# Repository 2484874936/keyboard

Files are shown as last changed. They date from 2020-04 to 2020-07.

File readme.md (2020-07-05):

**@版权所有->刘威**

**[SEASKY机械键盘演示视频](https://b23.tv/BV1ri4y1t7xG)**

**[程序完善，键盘部分完整功能视频，和普通键盘效果差不多](https://b23.tv/BV1Pz411z7MM)**

**software如果使用cube重新生成过程序，请用备份里的ST文件替换Middlewares目录下的ST文件**

**欢迎加入SEASKY开源技术交流群:893445794**

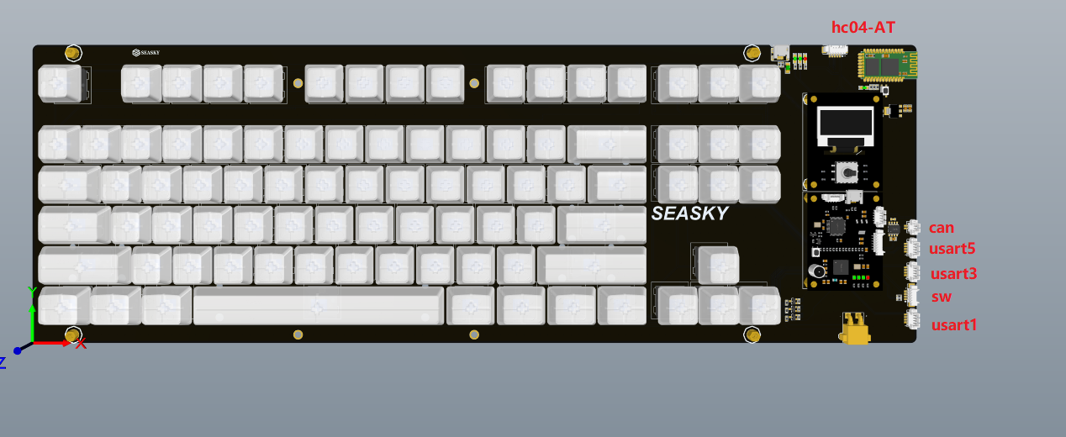
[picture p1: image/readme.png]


**说明：**
	上图所示引出接口，普通接口使用GH1.25，SWD调试接口使用MX1.25,如果你使用的J-link，或ST-link是2.54的，需要买相应的2.54转mx1.25的线，如果你使用其他烧录方式，具体自己了解，最后提醒一下，务必关注原理图接口线序，我做的接口基本兼容RoboMaster，注意蓝牙模块必须是HC04-HID模块

**下载说明：**
	因为有人反映github下载速度过慢，因此如果您有下载网速过慢的问题可以尝试使用码云[``https://gitee.com/``](https://gitee.com/)clone仓库后下载，码云下载github仓库的具体方法大家自行了解，很简单,同时由于仓库可能会更新软件，建议大家在github关注。
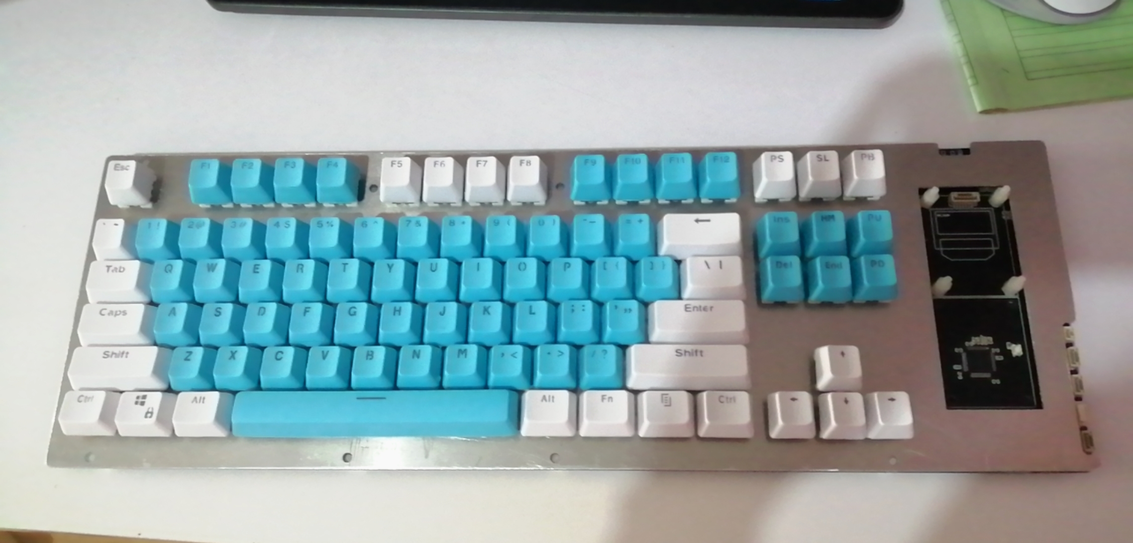
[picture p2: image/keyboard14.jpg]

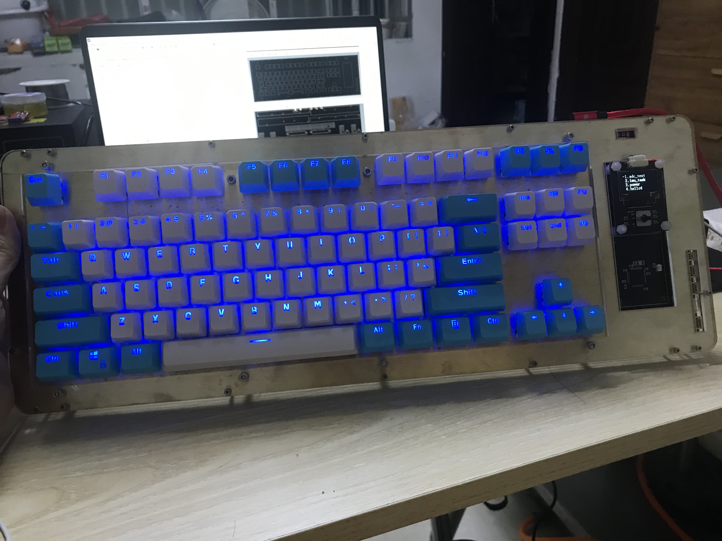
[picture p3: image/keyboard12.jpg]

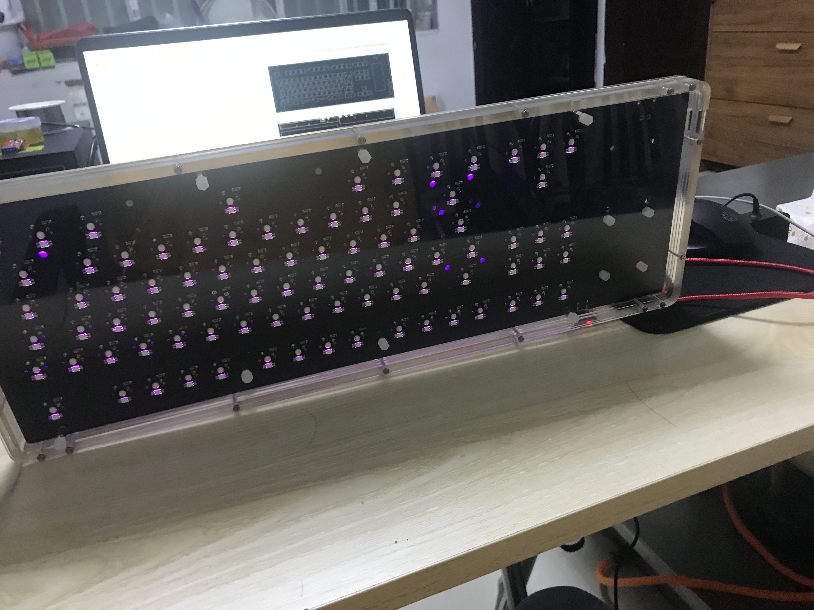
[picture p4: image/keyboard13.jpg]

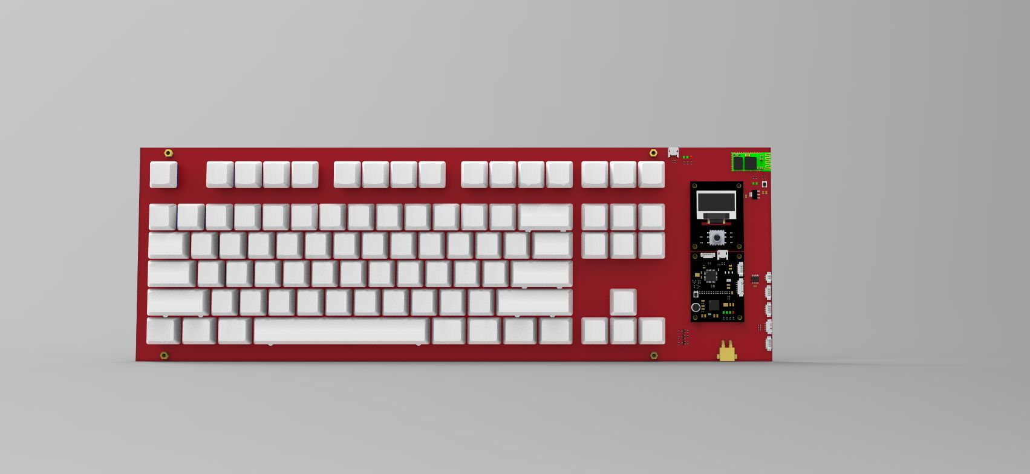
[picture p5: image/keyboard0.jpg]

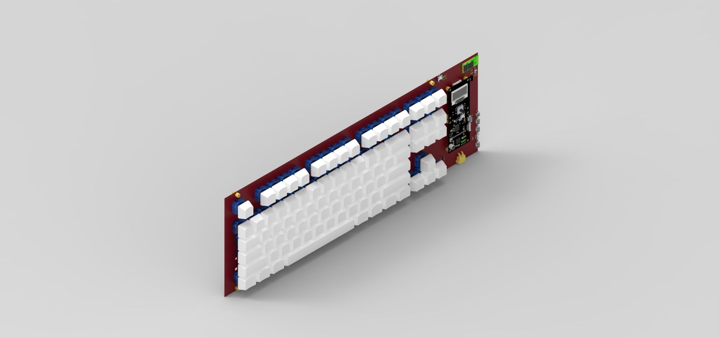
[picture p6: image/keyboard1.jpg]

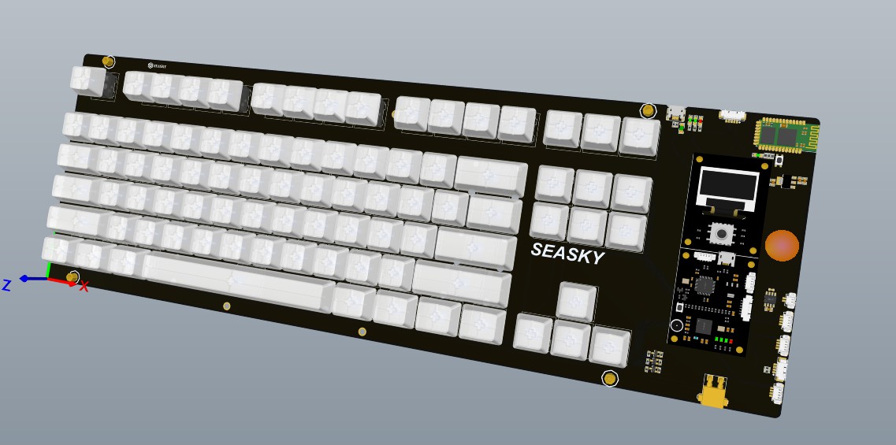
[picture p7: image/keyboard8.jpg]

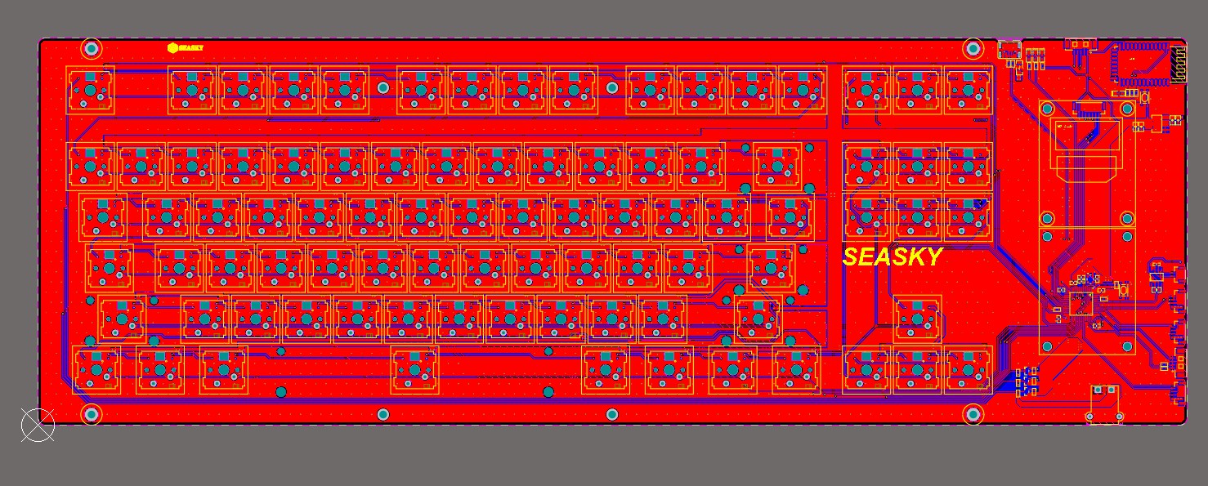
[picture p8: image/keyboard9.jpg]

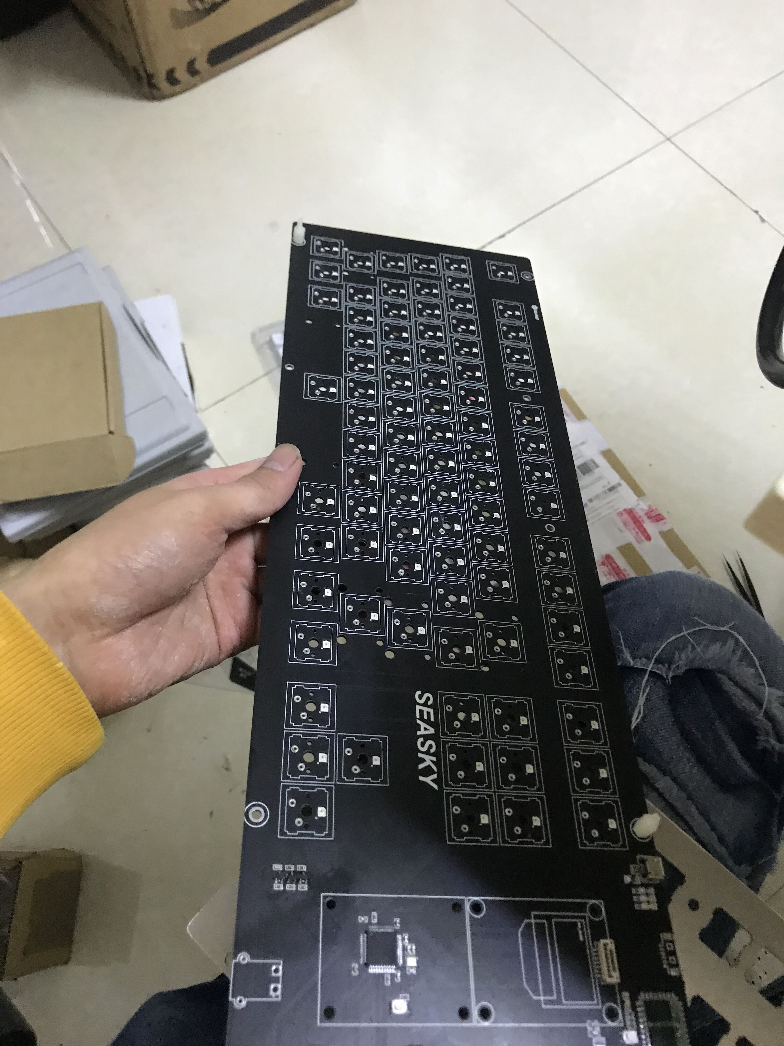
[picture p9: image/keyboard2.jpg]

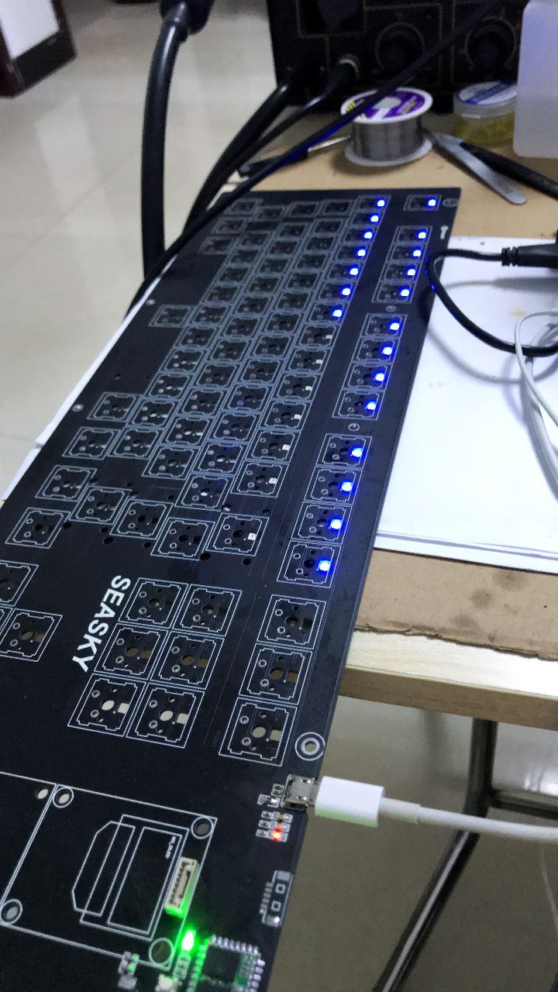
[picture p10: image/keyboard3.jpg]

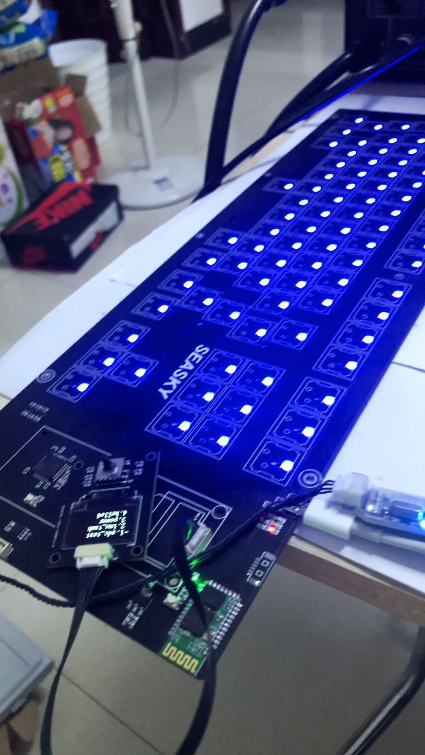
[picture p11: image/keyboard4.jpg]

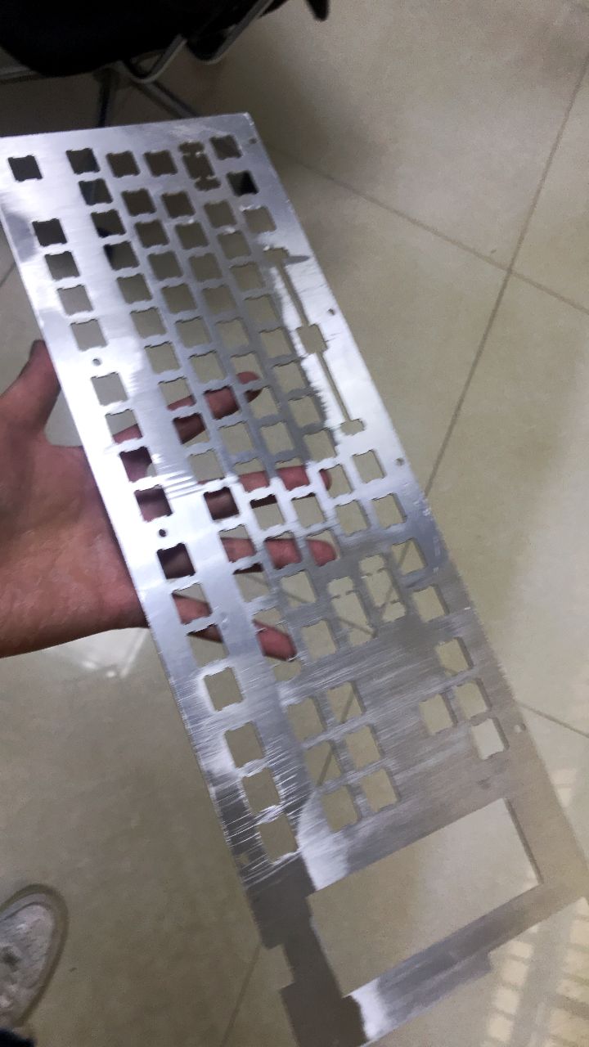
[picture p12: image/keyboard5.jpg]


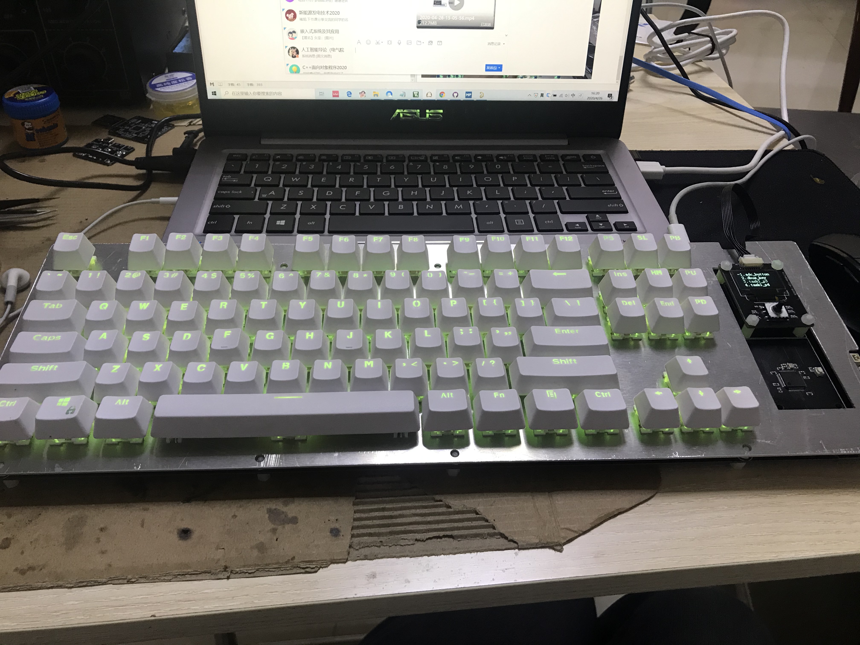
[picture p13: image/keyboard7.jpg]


**定位板：可以发加工黄铜定位板，铝定位板，此定位板可能需要自行修改一下，否则可能导致部分usb数据线无法接入**
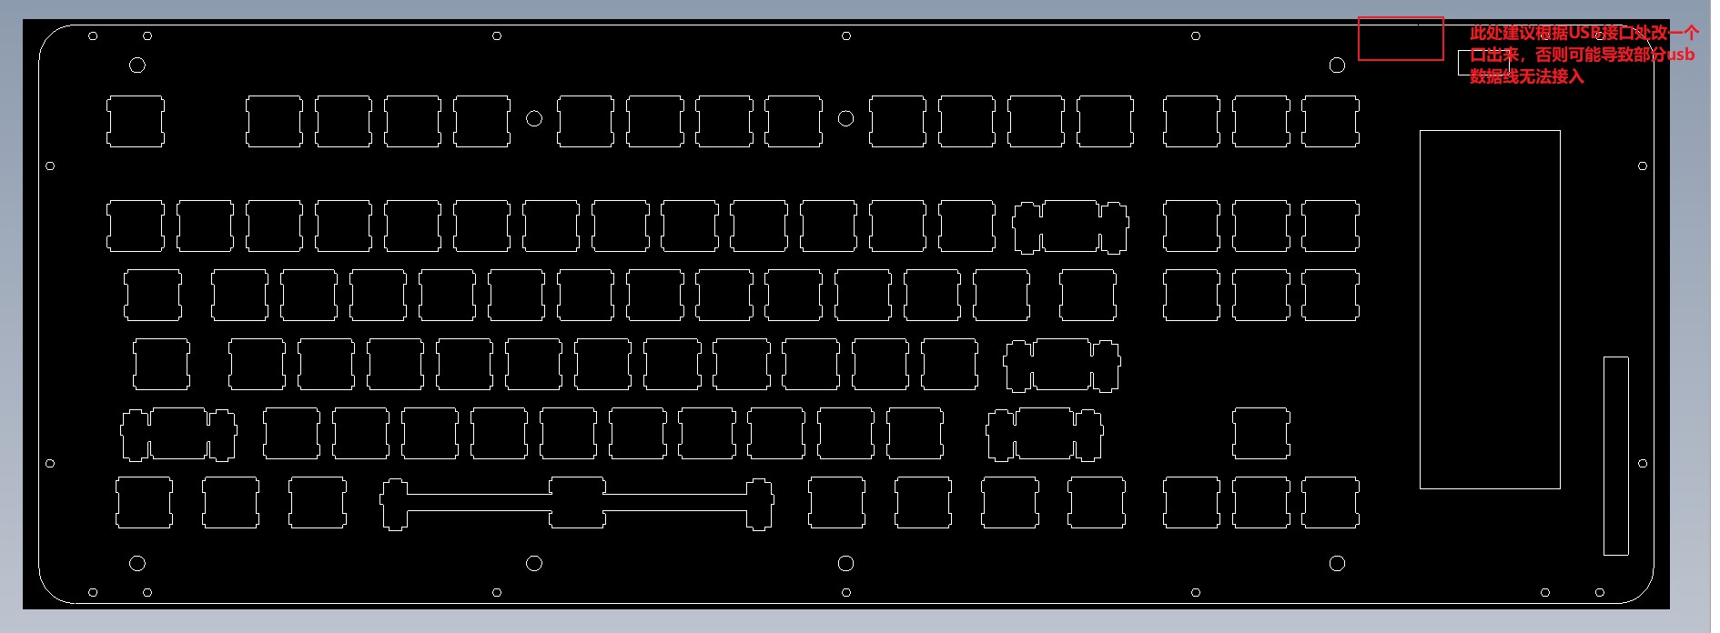
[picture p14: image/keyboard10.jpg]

**亚克力外壳：发亚克力加工 M2 M3螺丝**
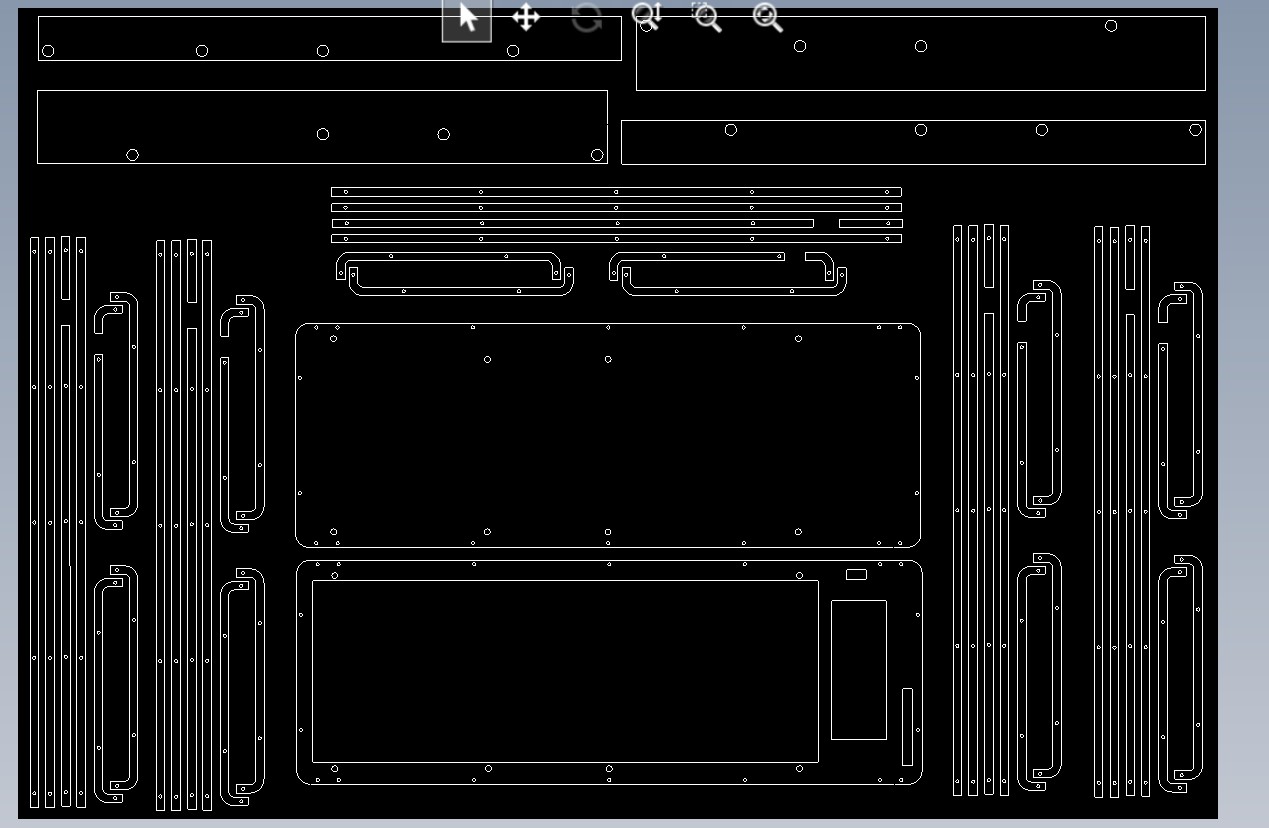
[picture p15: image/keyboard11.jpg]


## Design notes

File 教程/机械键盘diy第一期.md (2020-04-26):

##机械键盘DIY教程第一期
**@版权所有->SEASKY**

**LICENSE:** **MIT License**
##
> 看了一些网上的机械键盘diy教程，大都是用买的pcb和元件来焊接，pcb由联系厂家定制，现在我们来一个完全的，正真意义上的DIY教程，从元件选取，到PCB布局，再到焊接，完全可以自己一个人实现。
> 

#1.0原理部分
	1.1.本机械键盘选择使用stm32的usb-hid实现有线的hid键盘通信。
	1.2.选择使用蓝牙HID模块HC-04实现无线HID通信功能(具体情况淘宝搜索蓝牙HID模块就能找到啦)。
	1.3.键盘使用按键扫描。
	1.4.机械键盘看情况是否需要RGB灯效，我这里是做了RGB灯的选择的RGB是比较流行的WS2812B，封装选的和
	普通RGB大小一样的3512，当然为了能把LED贴在轴体里面还选择了反贴的3512封装，这个封装也可以叫6028，
	它相比比其他的优点:毫无疑问控制方面，节省IO资源；6028封装方便贴片。具体见后面分析。
	1.5.程序部分就不在这里说了。
	1.6.无线需要电源，我只留了接口，自己买个电池，做个dcdc到5v即可扩展。
	1.7.预留了一些接口包括OLED，串口，can等，方便扩展功能，我这里做的是一个LD3320语音识别模块。

#PCB绘制教程

----------

#1.首先需要找到机械键盘轴体的封装：


#上面是我从淘宝中找的图下面是pcb封装，pcb封装库我直接用的gh60的cherry轴元件库，大多数轴体都是兼容的
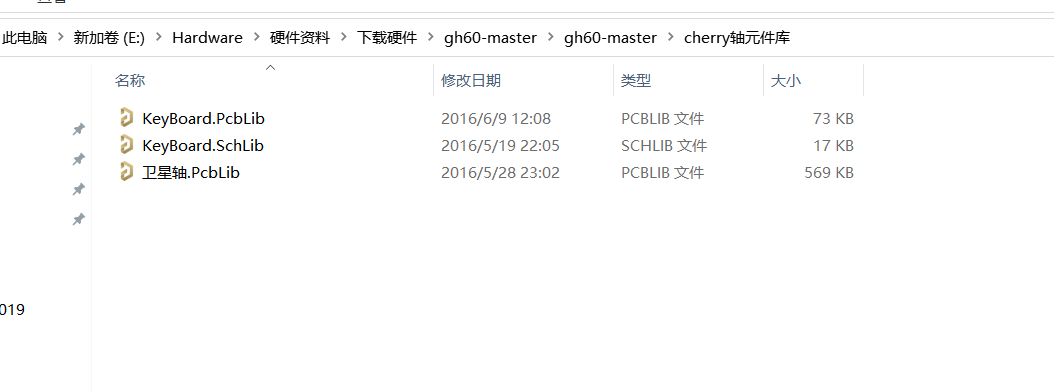
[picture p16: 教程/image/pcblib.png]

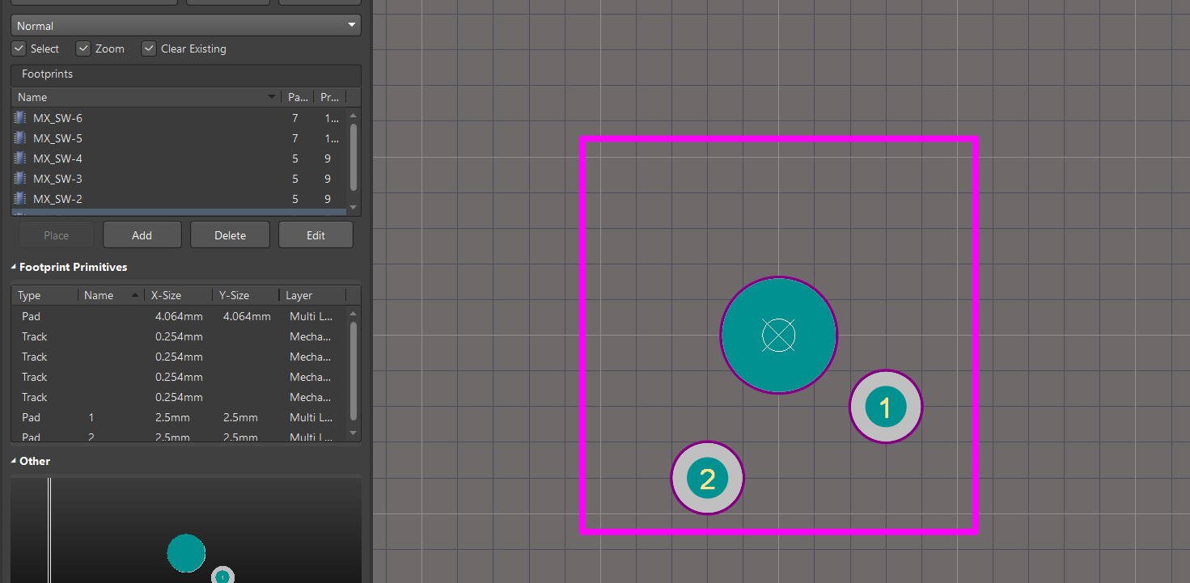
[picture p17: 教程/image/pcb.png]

#当然遗憾的是GH60开源的封装库里面没有3d封装，接下来我们需要稍稍更改一下这个，需要把3512led的封装集成到里面去
#更改前
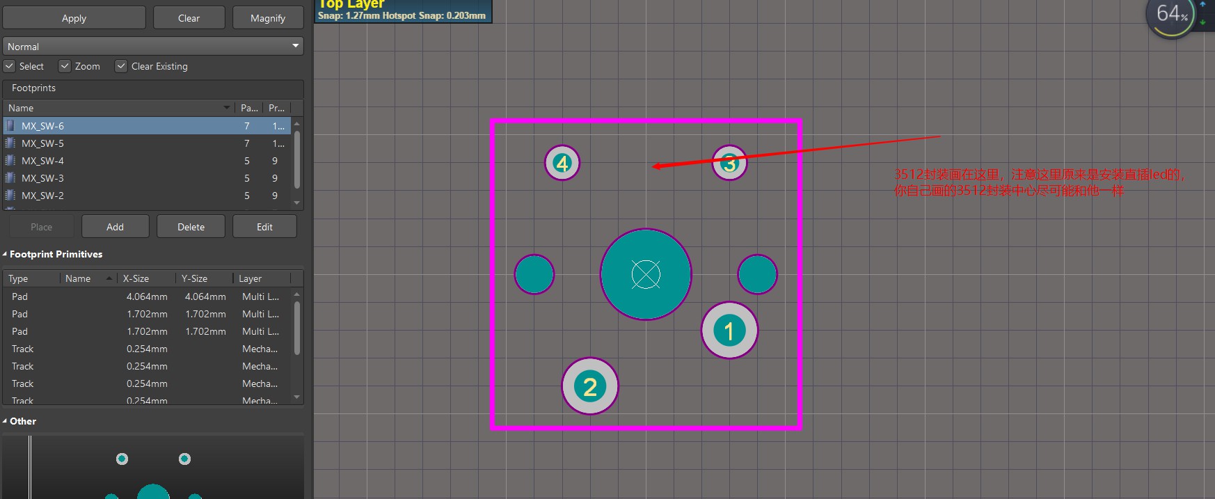
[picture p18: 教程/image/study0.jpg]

#更改后，注意3512贴背面，这也是为什么选择这个封装。
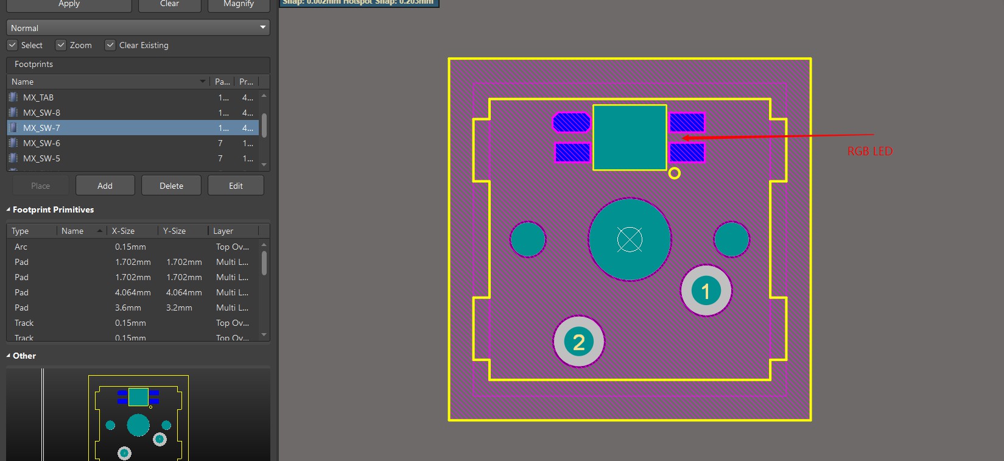
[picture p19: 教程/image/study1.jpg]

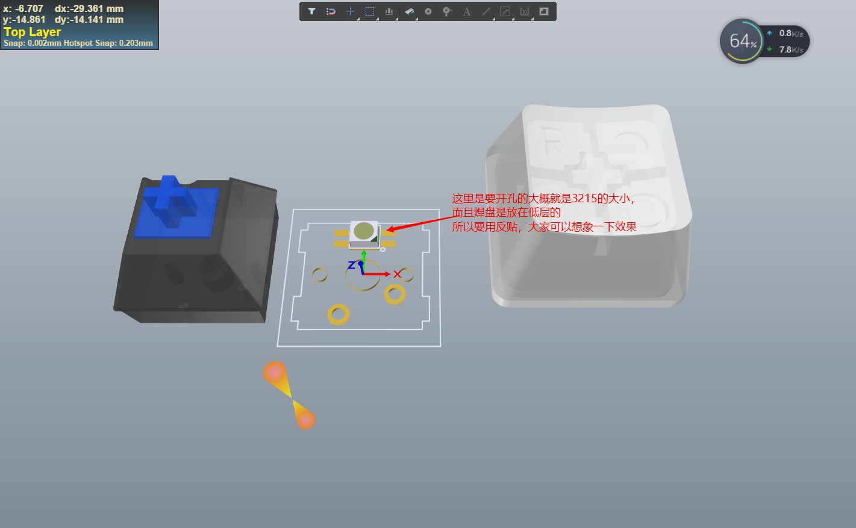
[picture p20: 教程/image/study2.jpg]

#至于3D封装嘛，自己画或者网上找，当然这个也只有3512后键帽是我自己画的，轴体的step网上能找到。关于画键帽的教材在后续教程，当然这个也不重要。

----------
#2.pcb布局部分，相信搜这个的大部分是关心机械键盘在pcb中怎么布局的问题，在这里我就先把轴体的布局讲一下：

##a.先了解两个网站
###keyboard-layout官网[http://www.keyboard-layout-editor.com/](http://www.keyboard-layout-editor.com/)
###和另一个网站[http://builder.swillkb.com/](http://builder.swillkb.com/)
###如果是ORCAD的话据说只需要上面的一个网站keyboard-layou
##b.大家先进入keyboard-layout官网[http://www.keyboard-layout-editor.com/](http://www.keyboard-layout-editor.com/)
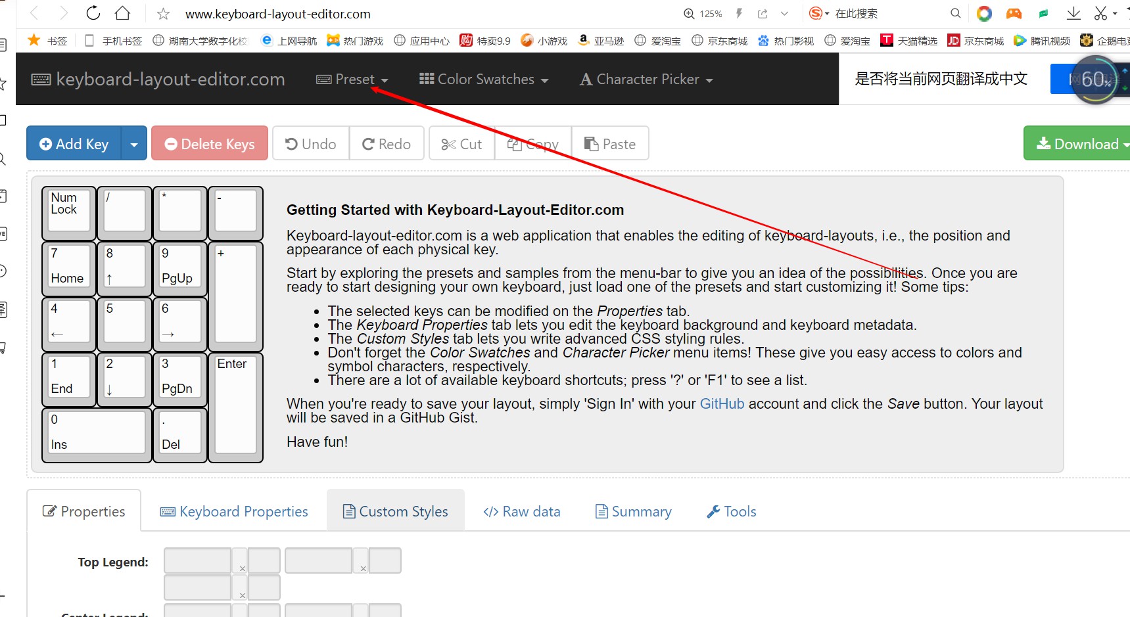
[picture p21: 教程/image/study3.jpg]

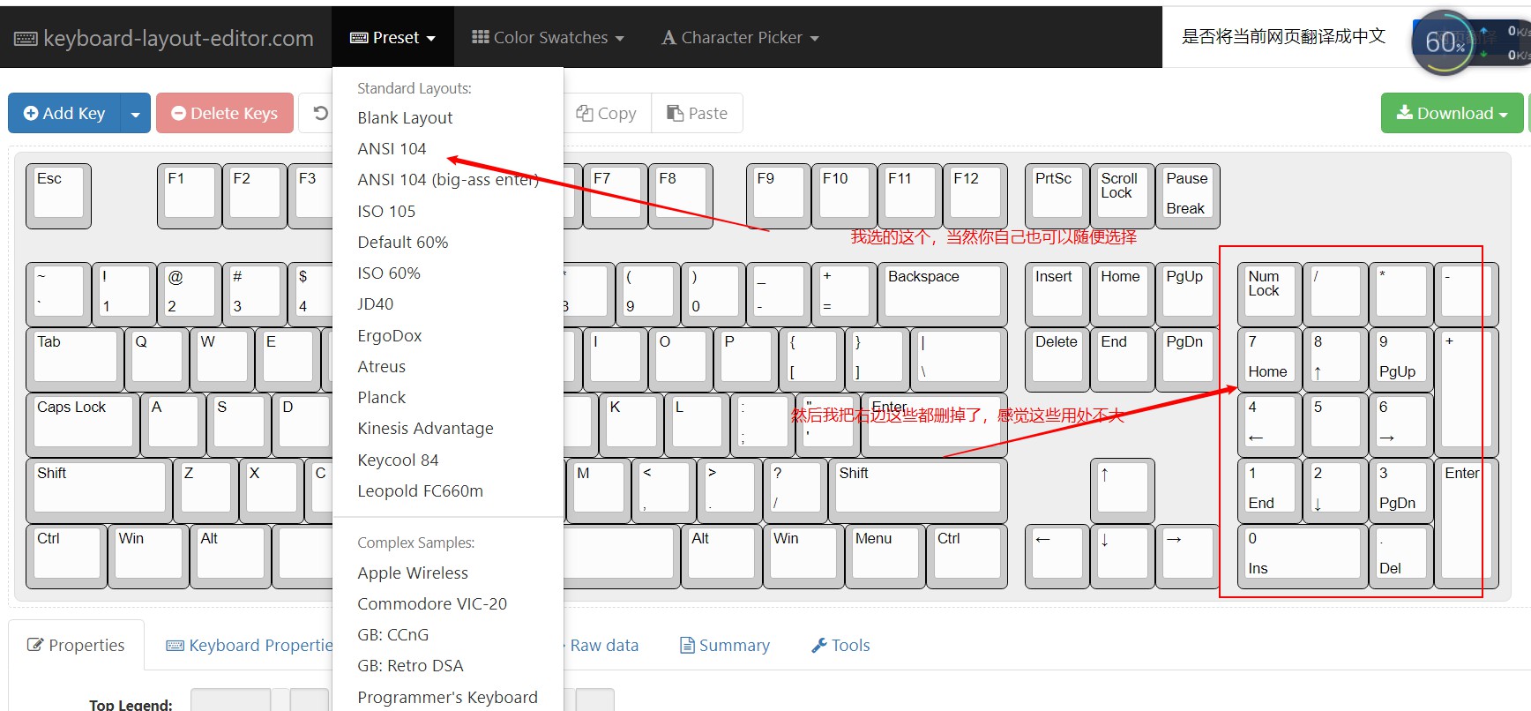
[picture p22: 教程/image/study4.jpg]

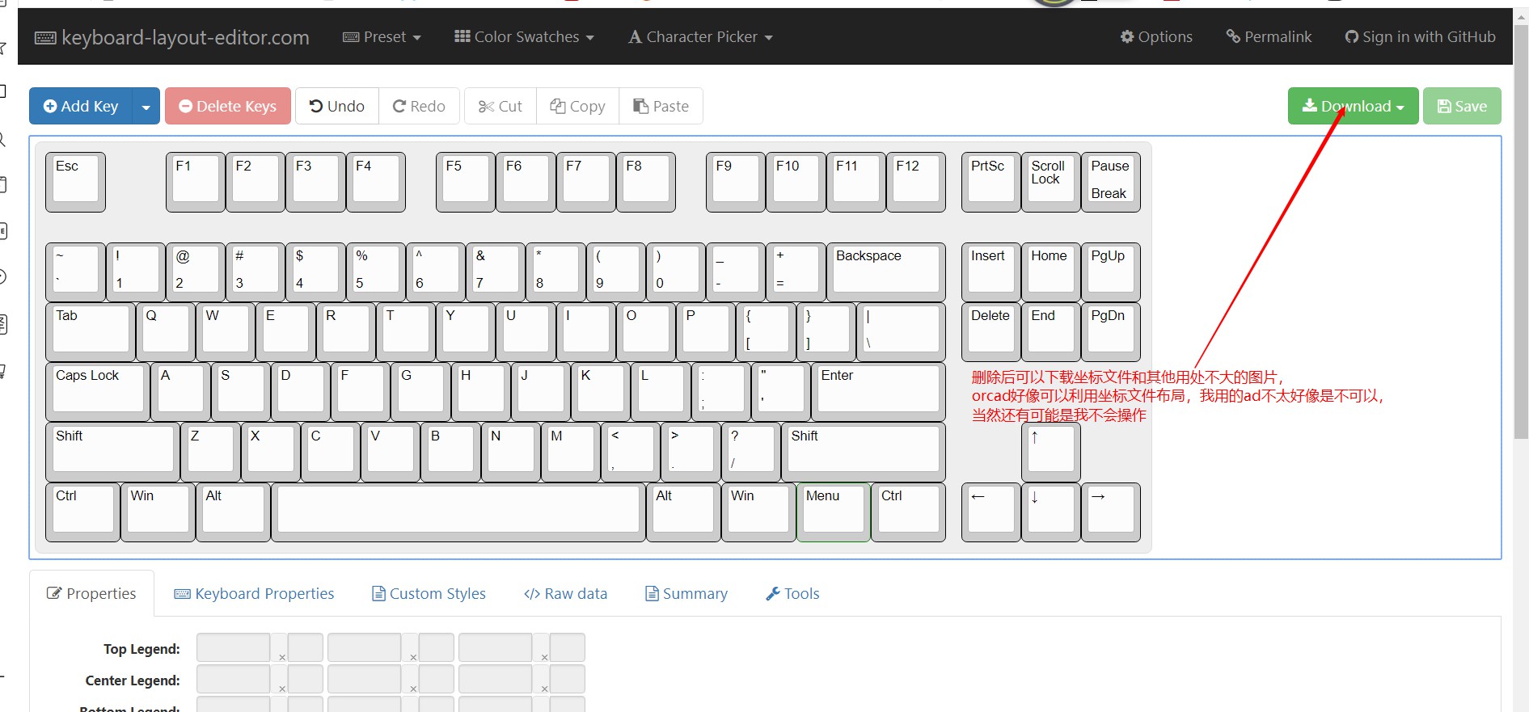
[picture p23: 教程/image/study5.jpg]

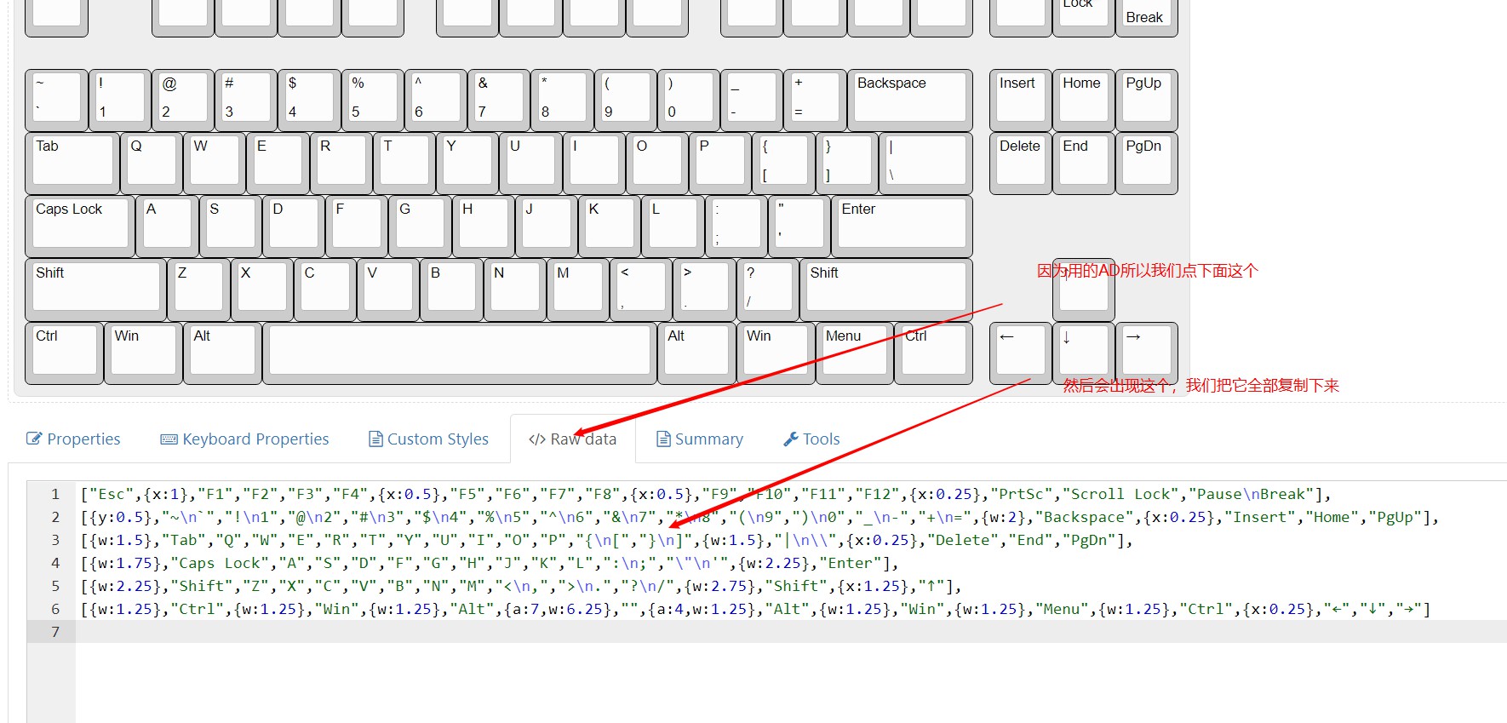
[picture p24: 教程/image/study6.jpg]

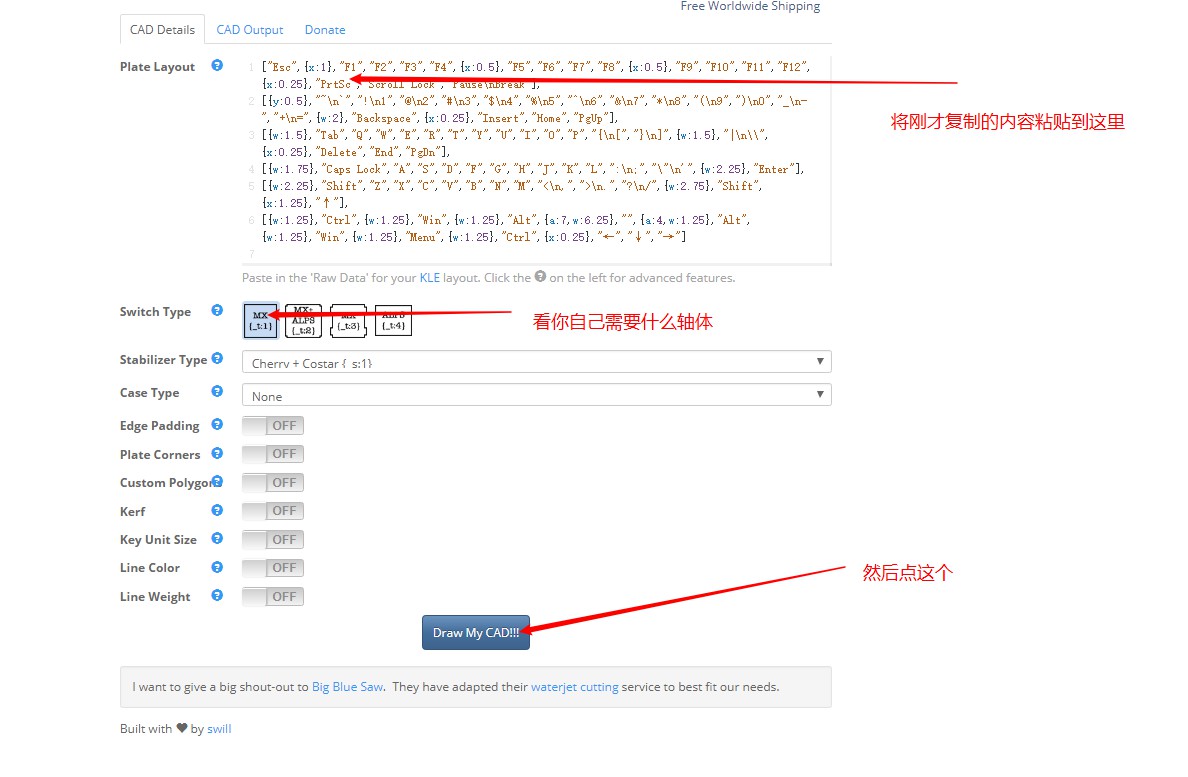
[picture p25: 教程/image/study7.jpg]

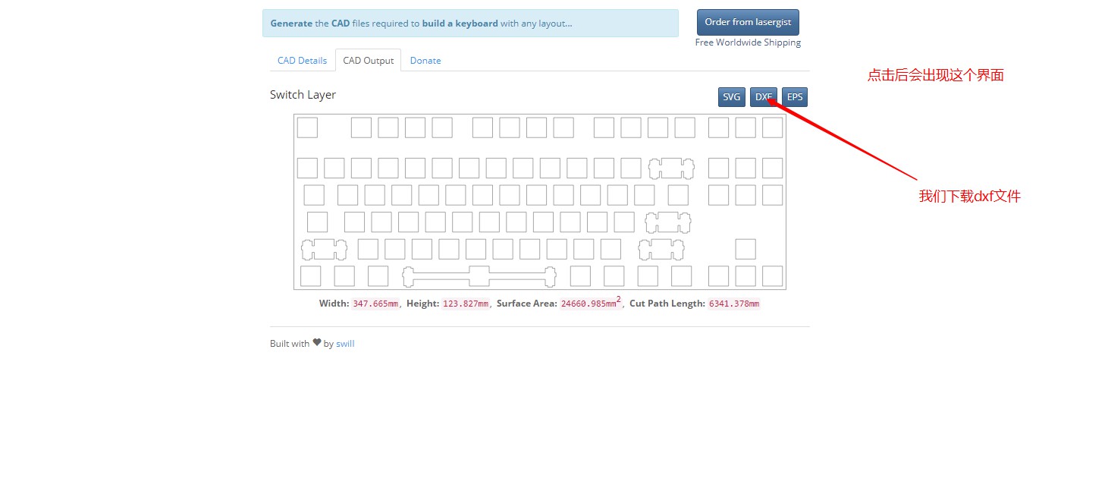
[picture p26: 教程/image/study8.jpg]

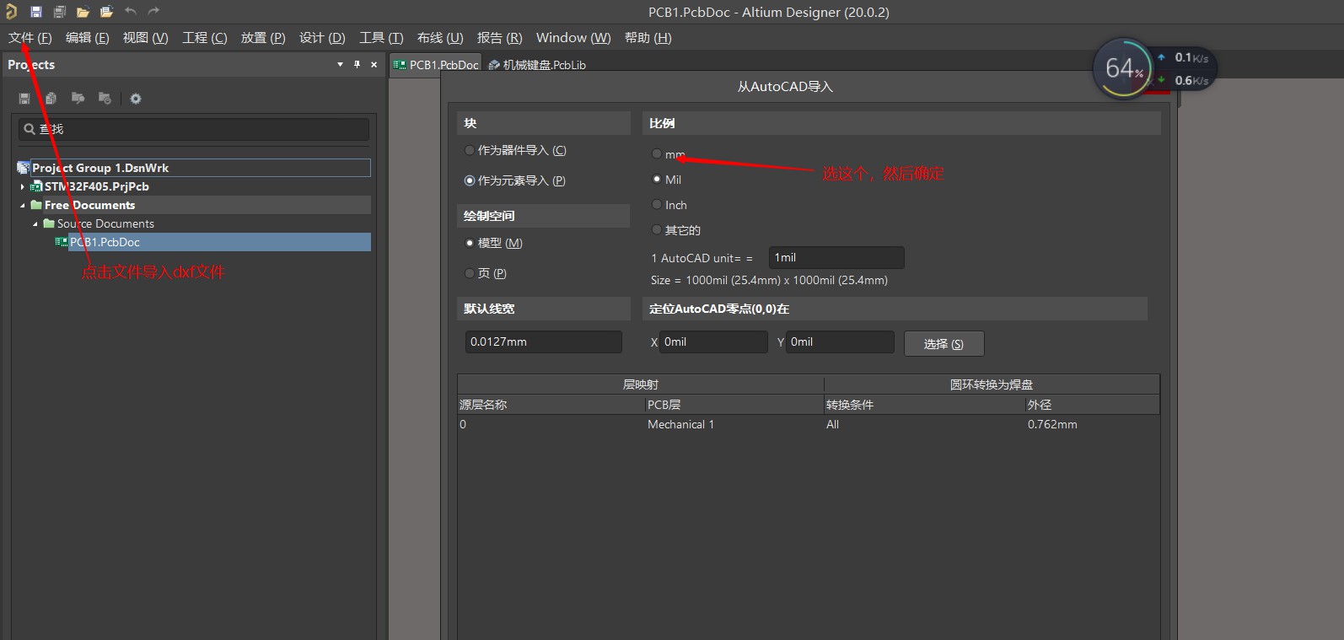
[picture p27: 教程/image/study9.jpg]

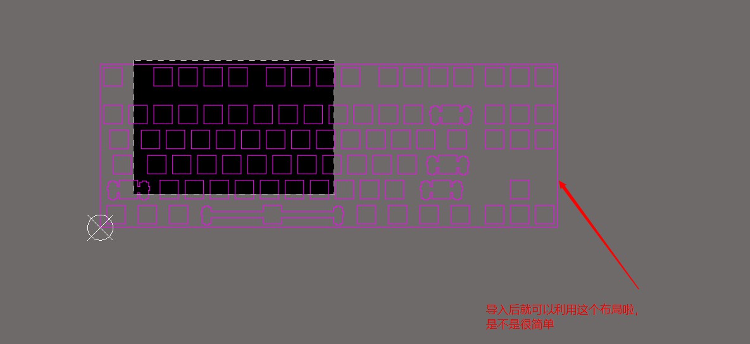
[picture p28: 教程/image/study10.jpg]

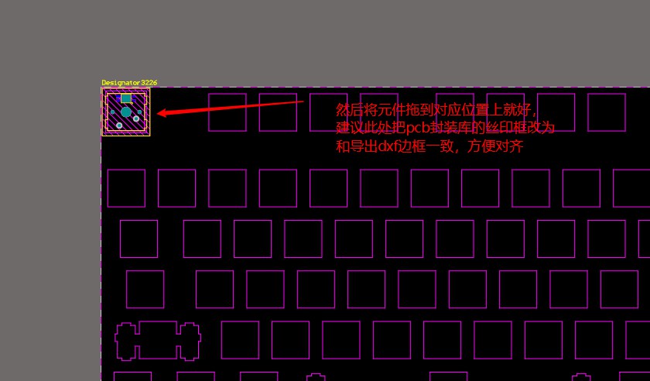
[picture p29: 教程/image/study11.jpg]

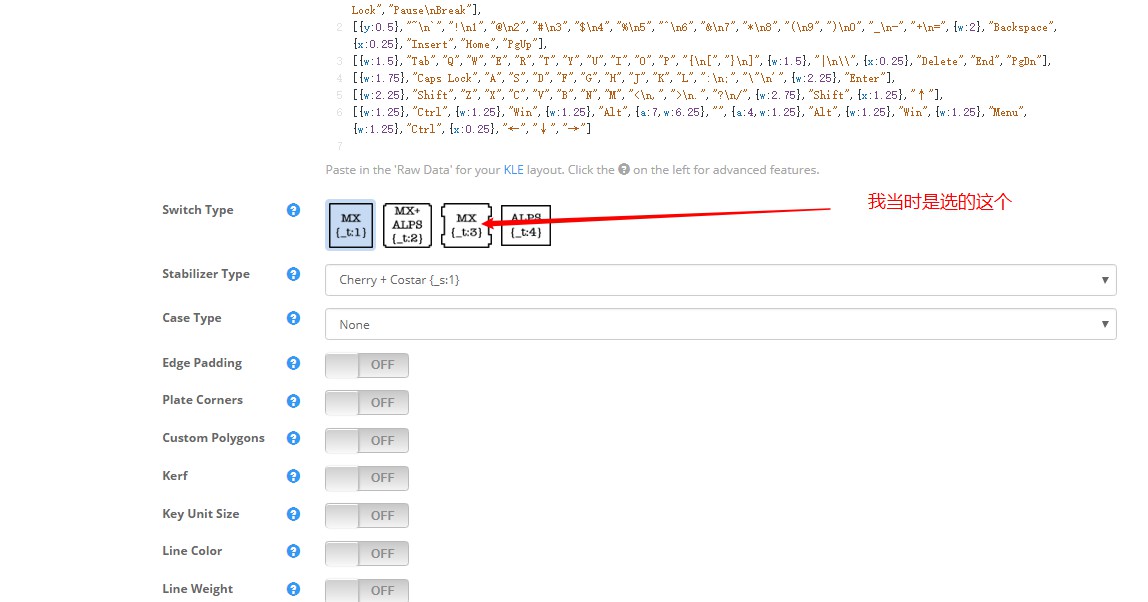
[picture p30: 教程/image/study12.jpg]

###感兴趣可以都导出对比一下，附上一张全部对比固定，放置后ad中务必选择固定，避免重复劳动
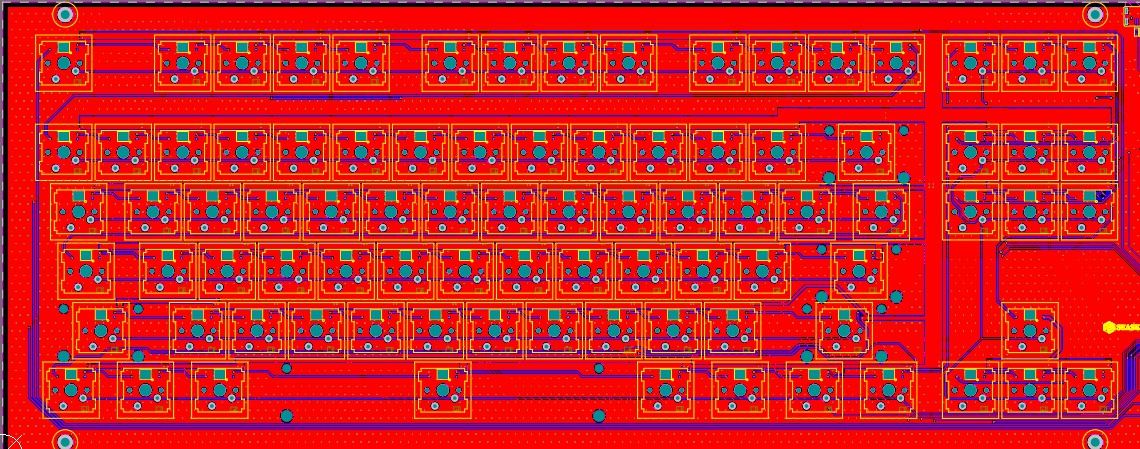
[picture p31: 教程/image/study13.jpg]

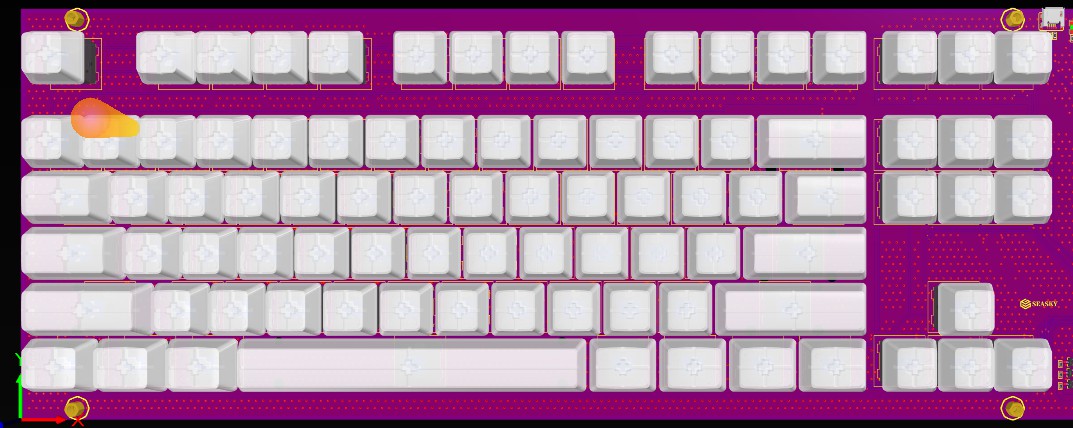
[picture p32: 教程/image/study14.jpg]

###注意像空格键，shift键这些还要留一个支架的固定孔，算了就叫支架吧，不记得名字了，这个支架的封装在cherry轴元件库里面可以找到

----------
#3.原理图部分：
###a.芯片选型如果用stm32f1的话，感觉扩展性不大，所以选型方向我们选择f4，在f4里面我们选择了成本较低性能较强的stm32f405芯片.
###b.引脚分配，直接在stm32cube_mx上分配了，看手册太不直观了，分配如下。
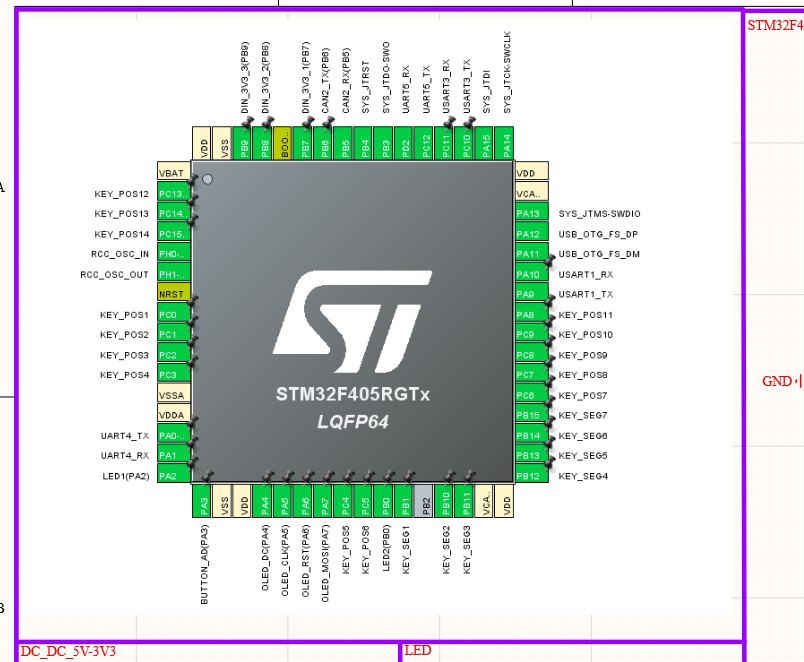
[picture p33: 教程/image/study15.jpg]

####stm32f405核心部分
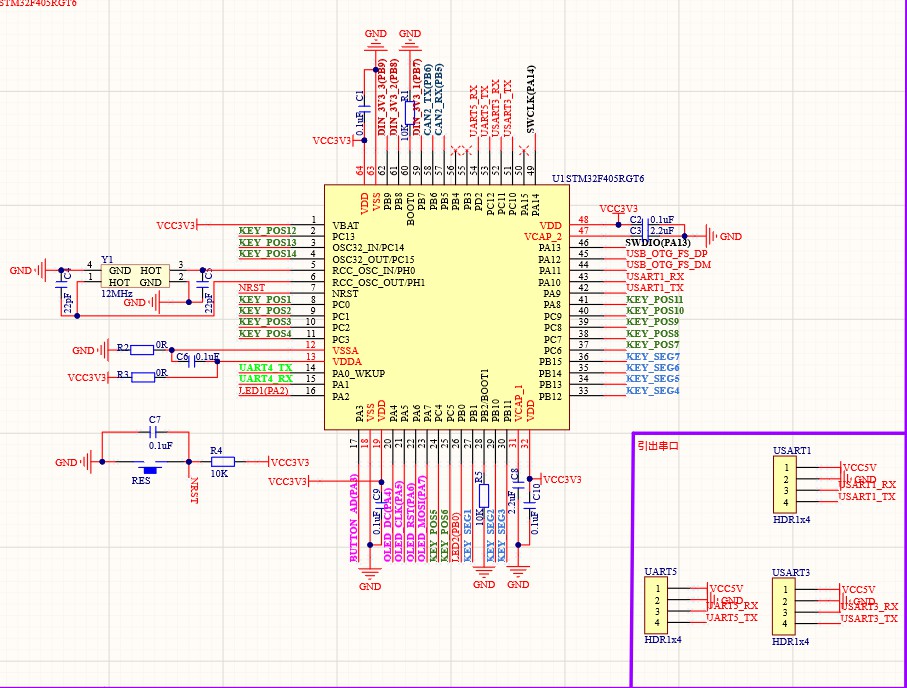
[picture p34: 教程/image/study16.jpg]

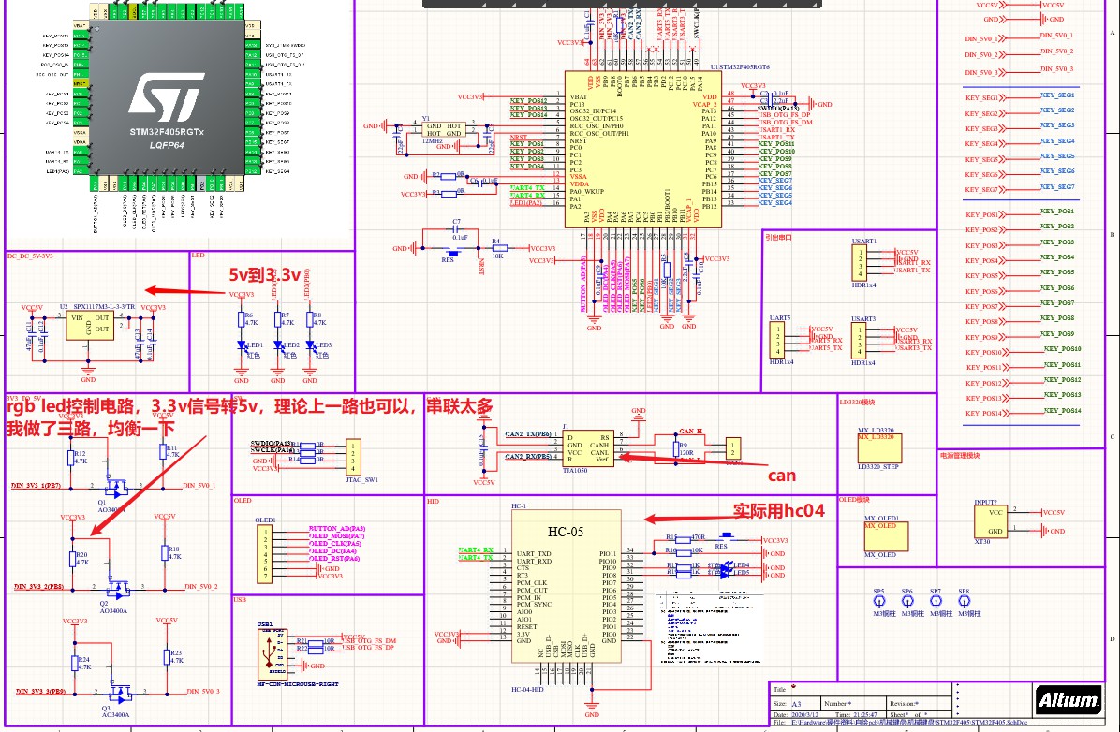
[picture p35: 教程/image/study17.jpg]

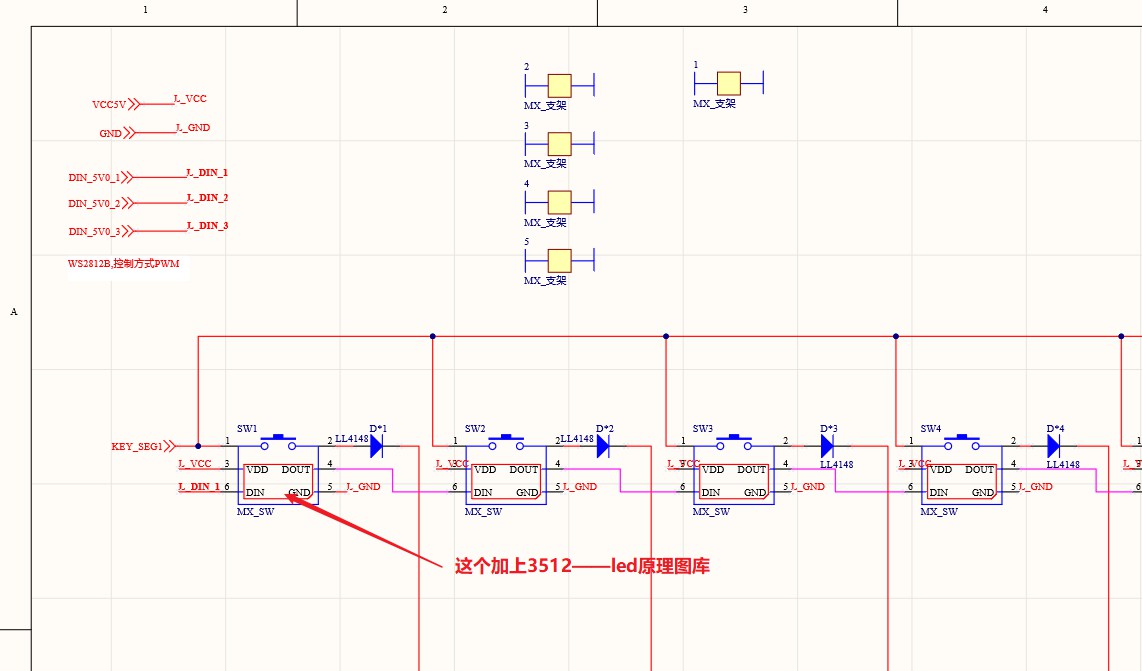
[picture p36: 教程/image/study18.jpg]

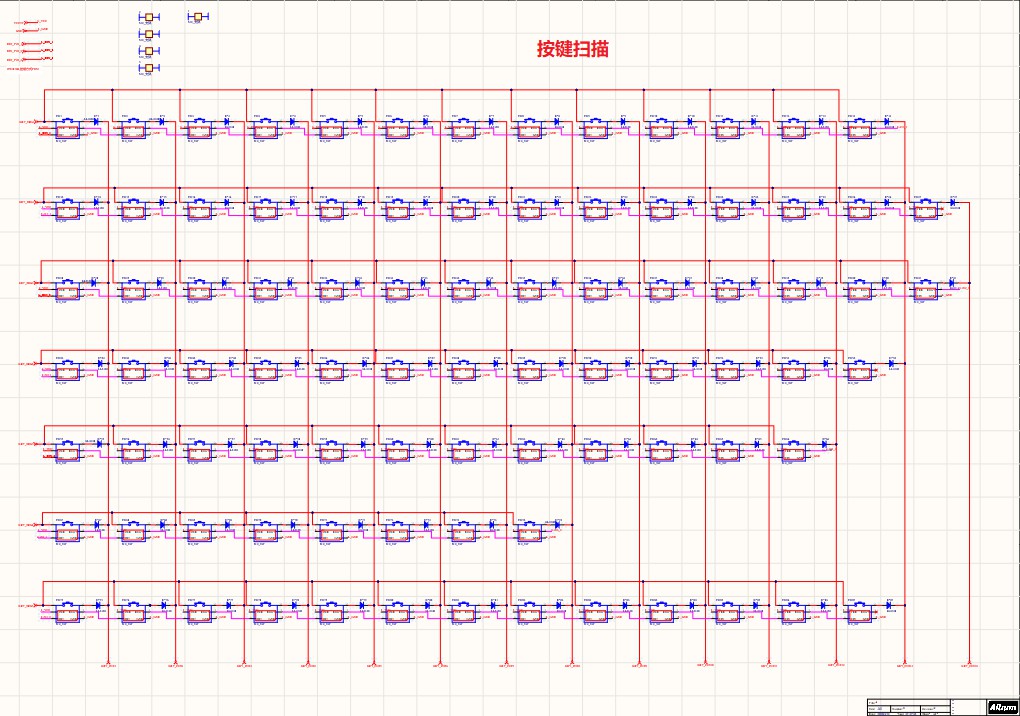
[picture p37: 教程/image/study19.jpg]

#4.pcb布线结果：
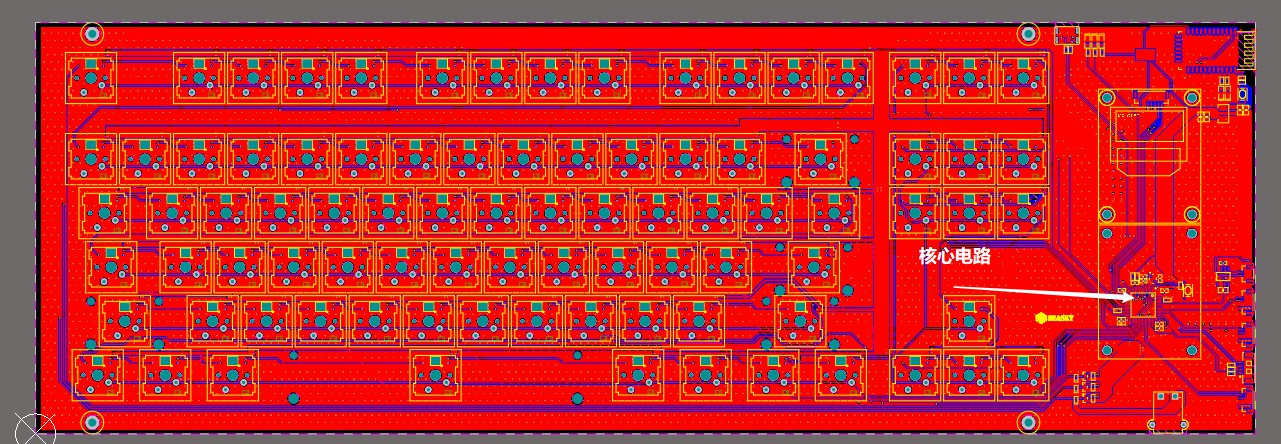
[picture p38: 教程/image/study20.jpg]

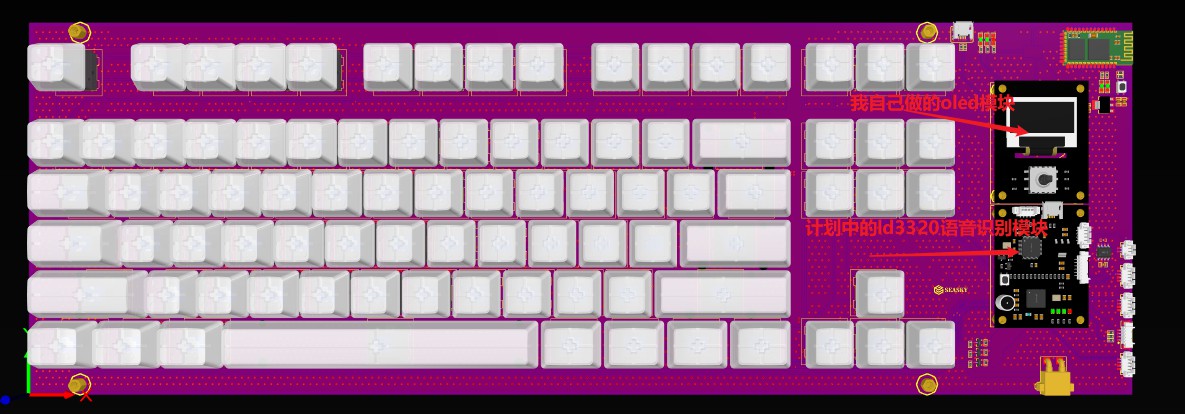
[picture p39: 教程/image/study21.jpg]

###自己附加做了OLED模块，OLED完美兼容大疆ROBOMASTER的OLED，已经用了很久了；另一个就是LD3320语音识别模块，当然被困在家嘛，没法检验，LD3320语音识别模块上面还预留了指纹识别模块接口的，意味着LD3320模块不仅支持语音识别，还支持语音识别，这个模块主要是用来魔改机械键盘的。

#原理图开源了，PCB暂时不开源，需要等到检验后开源

#附上几张3d渲染图



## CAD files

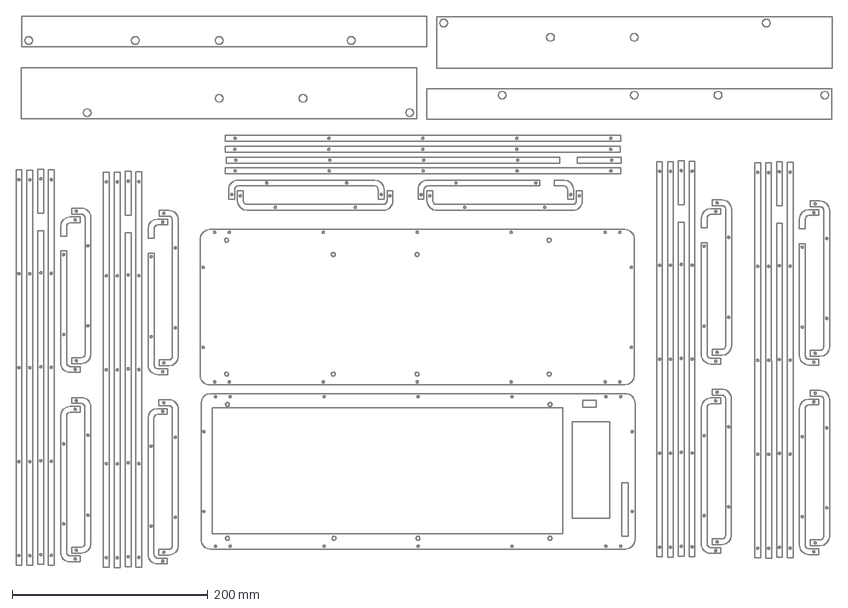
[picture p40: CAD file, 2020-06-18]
DXF/加工/亚克力.DXF
834.8 x 563.7 mm

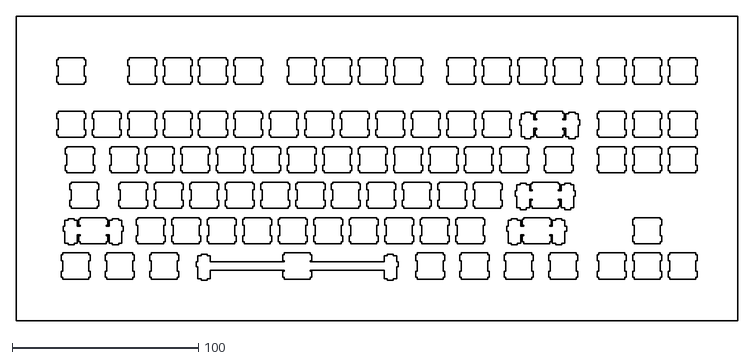
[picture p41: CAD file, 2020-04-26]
键盘布局/4987ada2df00cb1a070adbff16d729f80f7aeb5b_switch.dxf
387.7 x 163.8

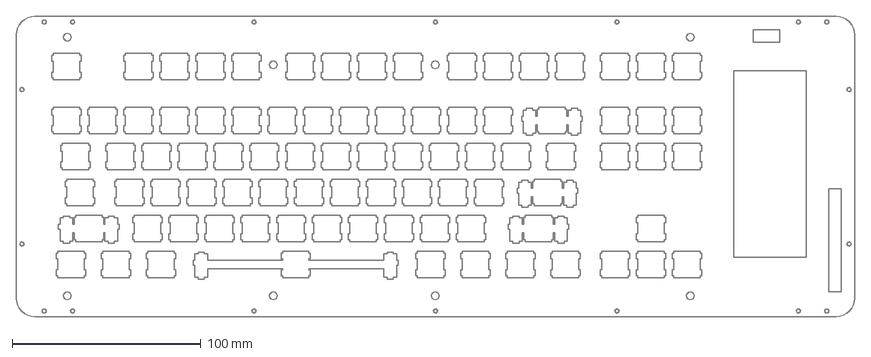
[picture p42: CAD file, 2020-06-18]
DXF/加工/定位板_v2.DXF
444.0 x 159.0 mm

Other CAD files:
DXF/定位板_V2.DXF
DXF/加工/亚克力.SLDDRW
DXF/加工/定位板_1.5mm.SLDDRW

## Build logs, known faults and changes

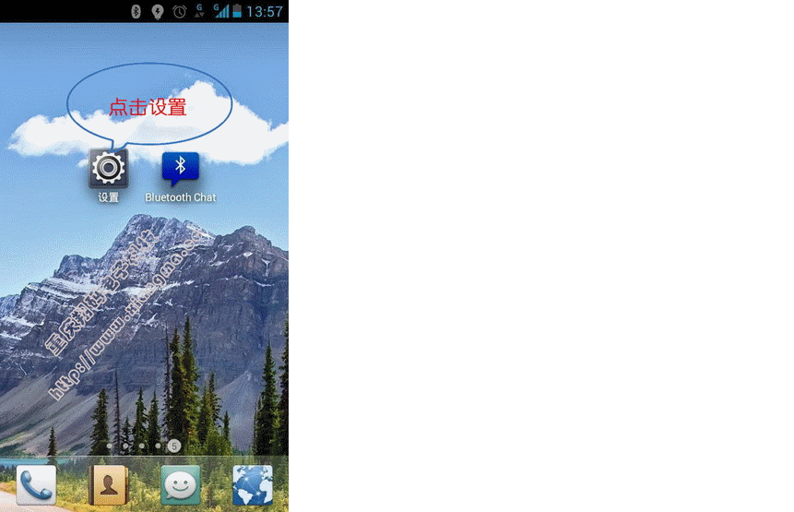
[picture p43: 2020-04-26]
参考资料/XM-04-HID/XM-04-HID/XM-15B/XM-15B/FAQ/手机配对连接通信演示.gif

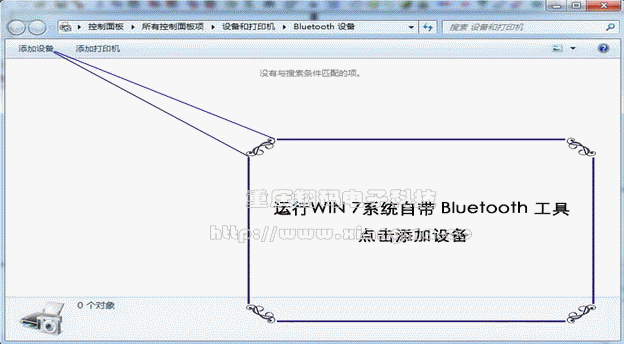
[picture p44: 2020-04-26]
参考资料/XM-04-HID/XM-04-HID/XM-15B/XM-15B/FAQ/Win7配对连接通信演示.gif

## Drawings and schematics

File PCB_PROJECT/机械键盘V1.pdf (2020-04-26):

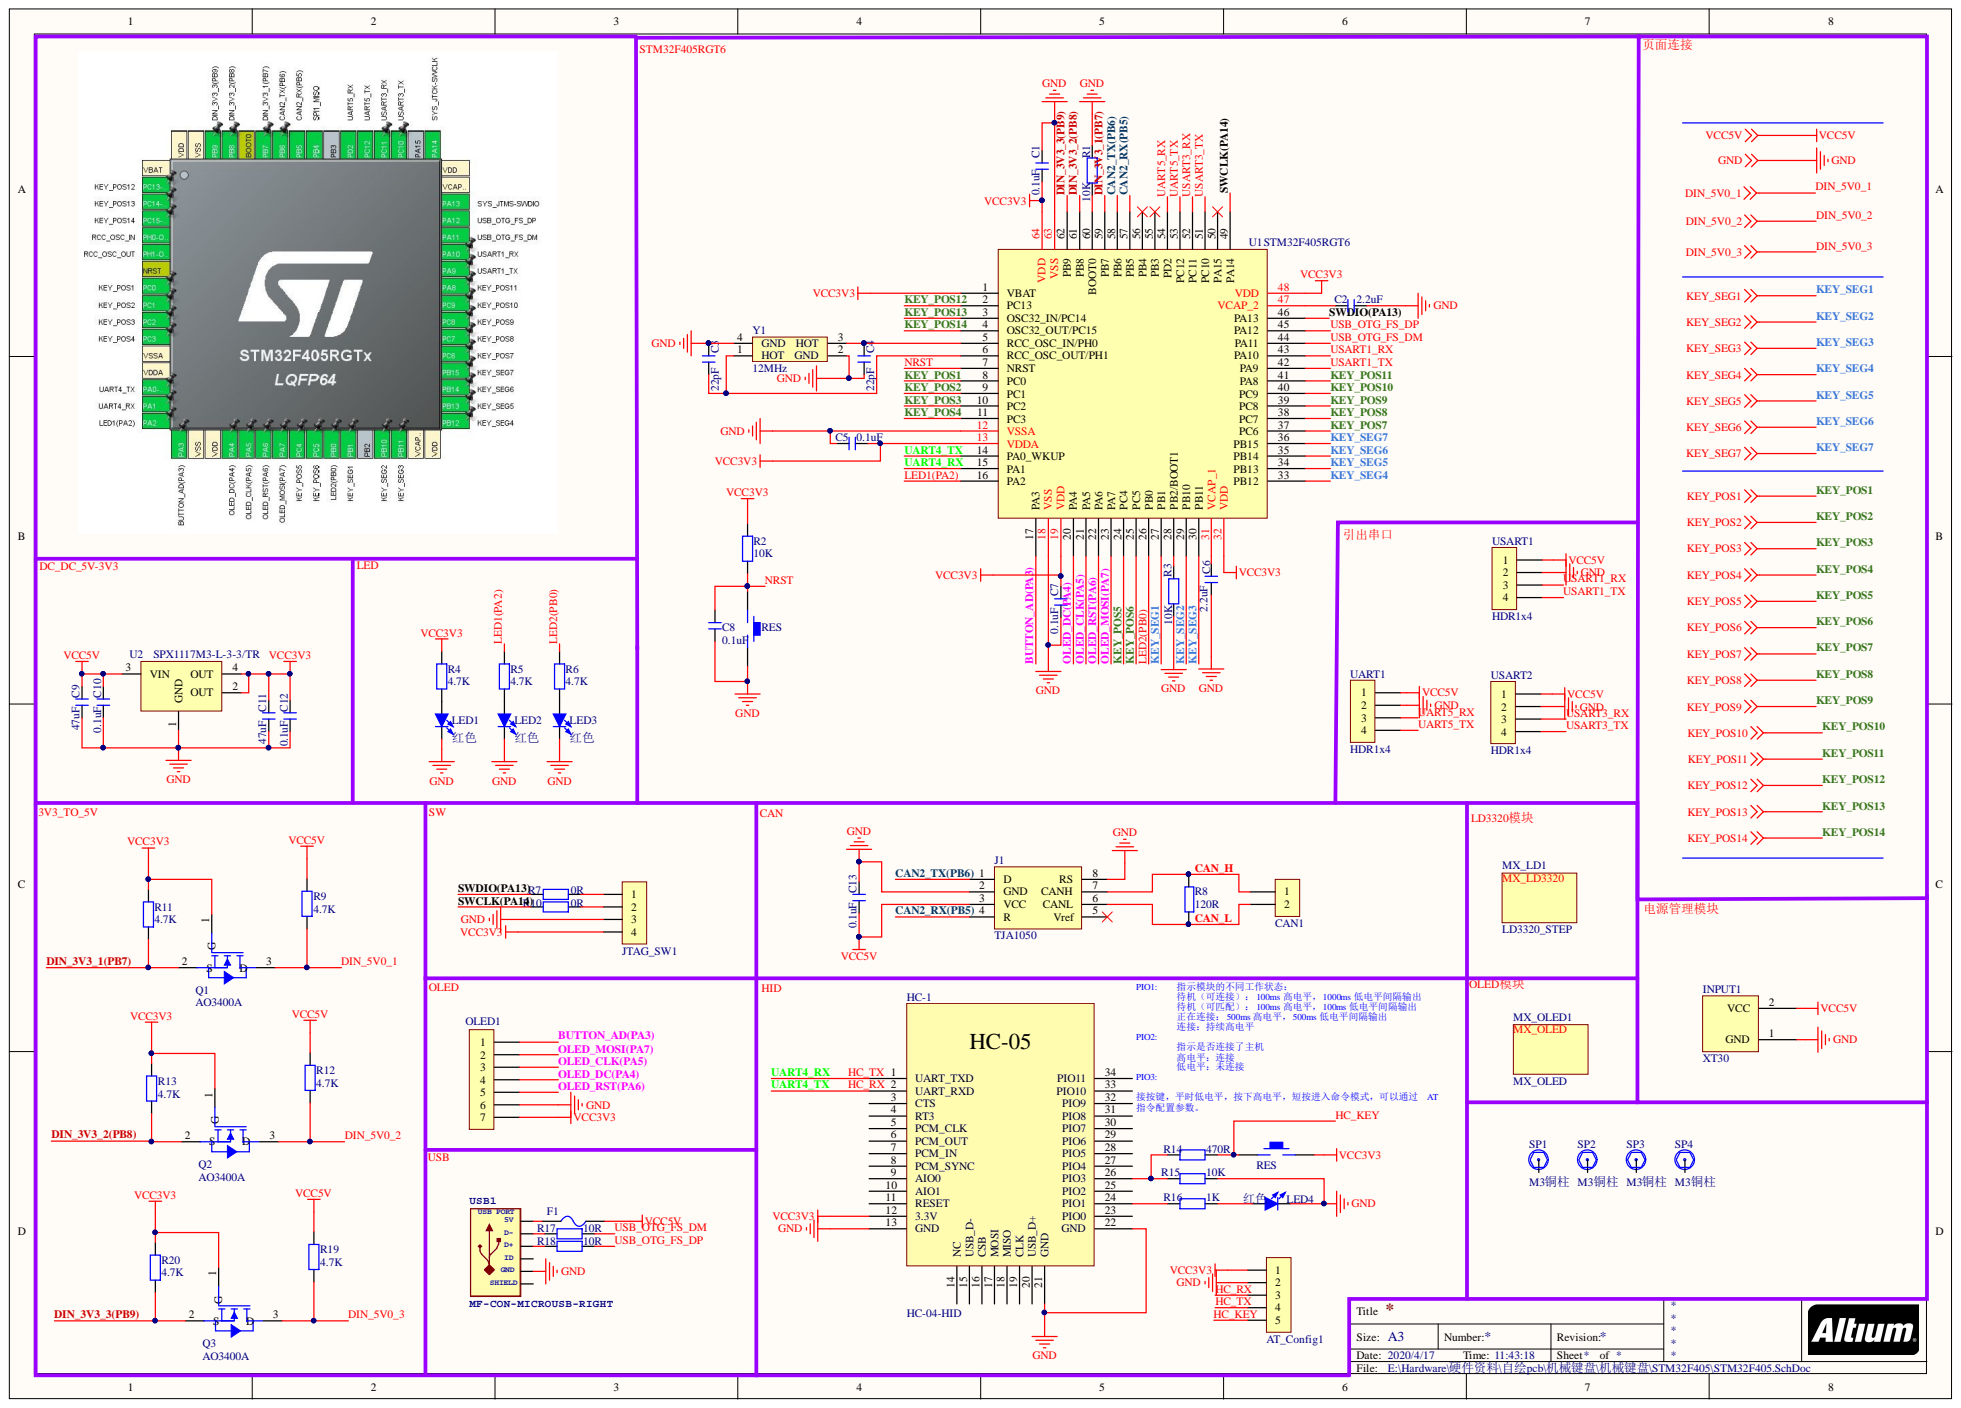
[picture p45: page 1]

C5 0.1uF | VDDA 13

UART4_TX | PA0_WKUP 14

待机（可连接）： 100ms 高电平，1000ms 低电平间隔输出
待机（可匹配）： 100ms 高电平，100ms 低电平间隔输出
正在连接：500ms 高电平，500ms 低电平间隔输出
连接：持续高电平

PIO3:
接按键，平时低电平，按下高电平，短按进入命令模式，可以通过 AT
指令配置参数。

MF-CON-MICROUSB-RIGHT

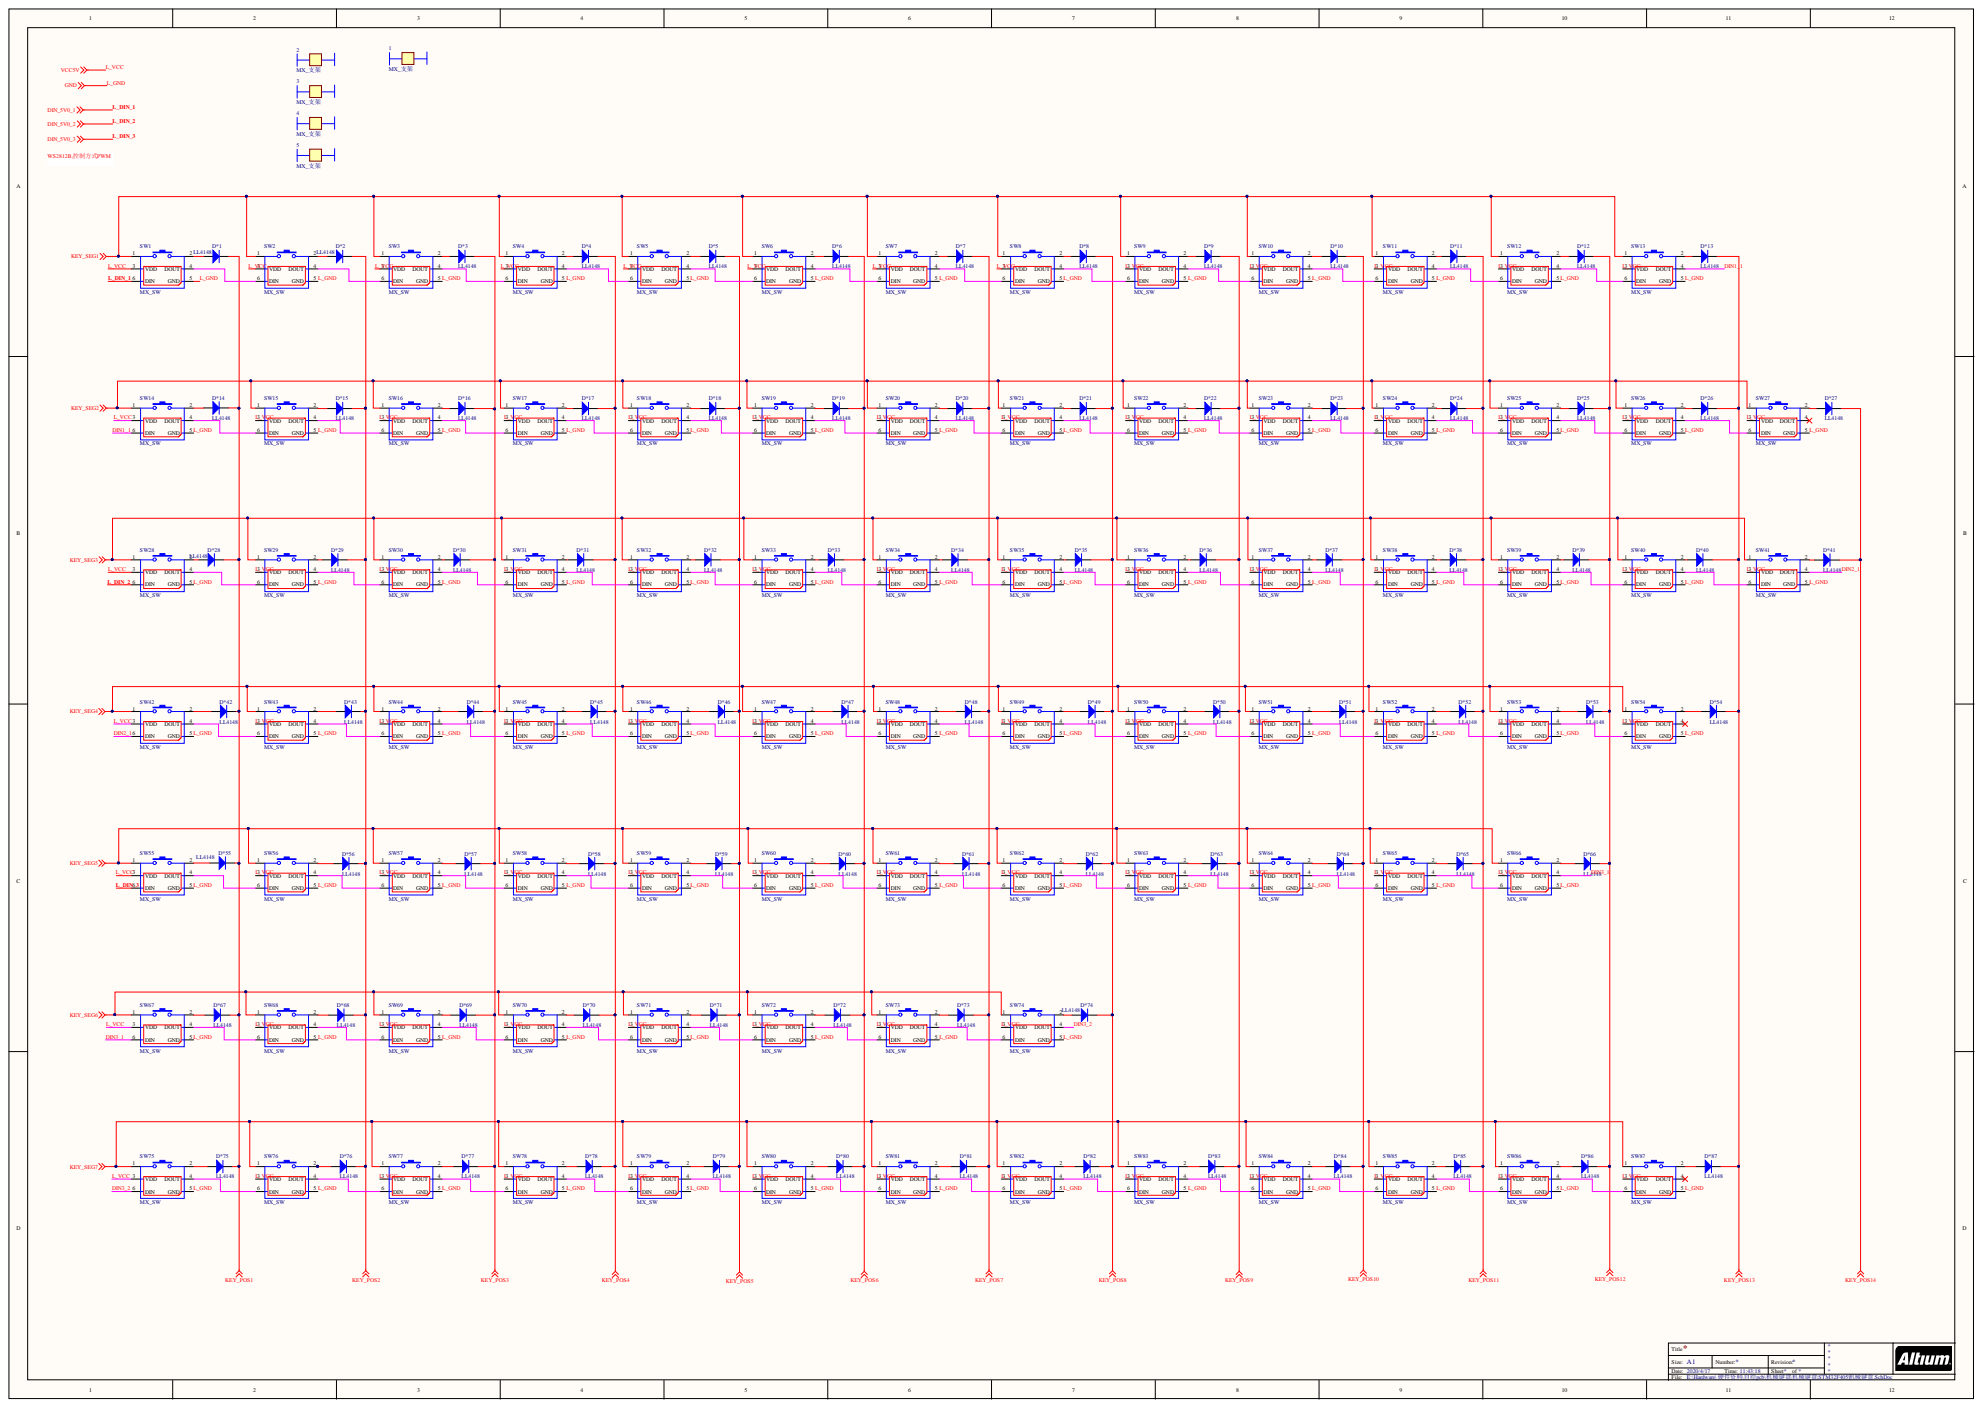
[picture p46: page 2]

Title * | * * * * *

Size: A1 | Number: * | Revision: *

Date: 2020/4/17 Time: 11:43:18 | | Sheet * of *

E:\Hardware\ 硬件资料\自绘pcb\机械键盘\机械键盘\STM32F405\机械键盘.SchDoc

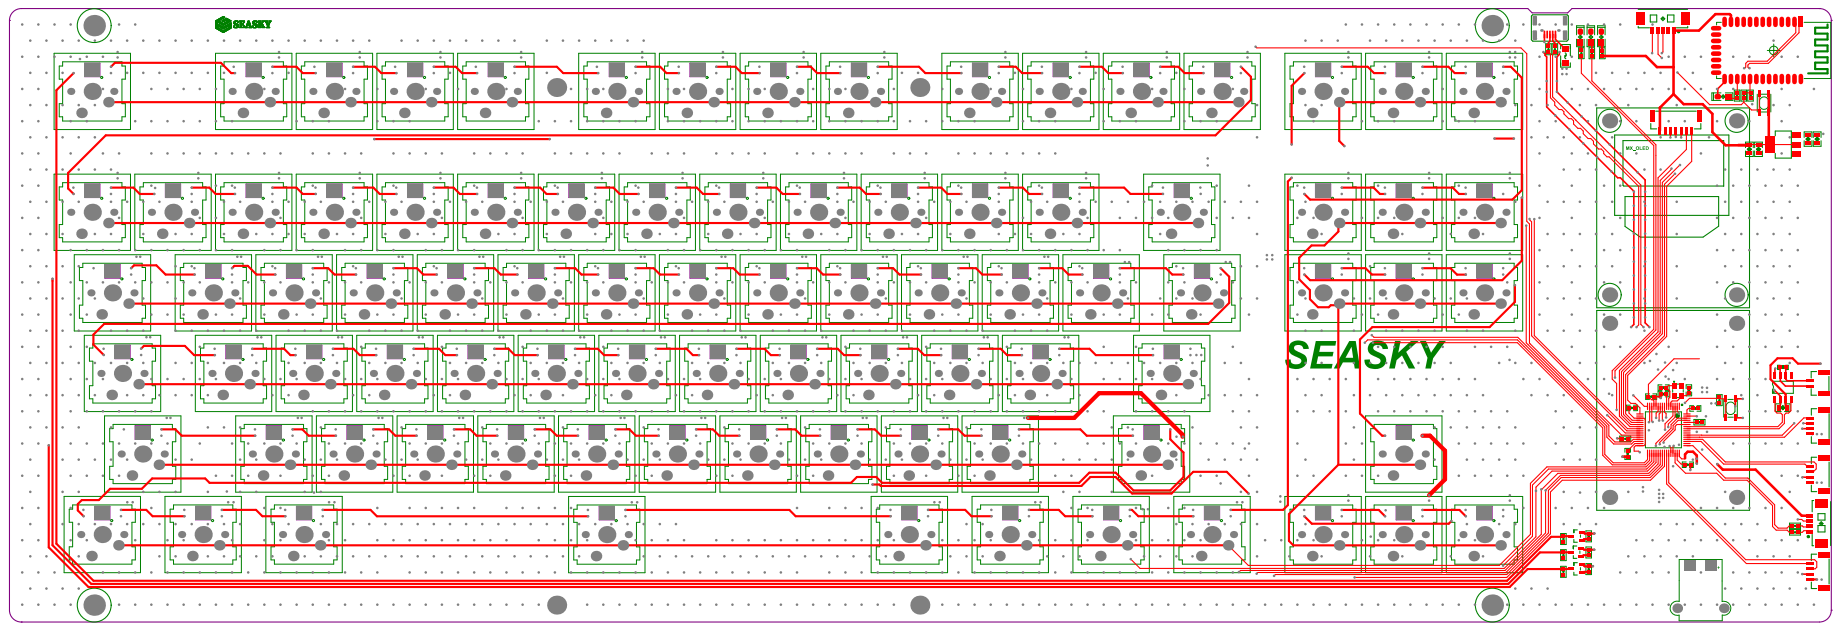
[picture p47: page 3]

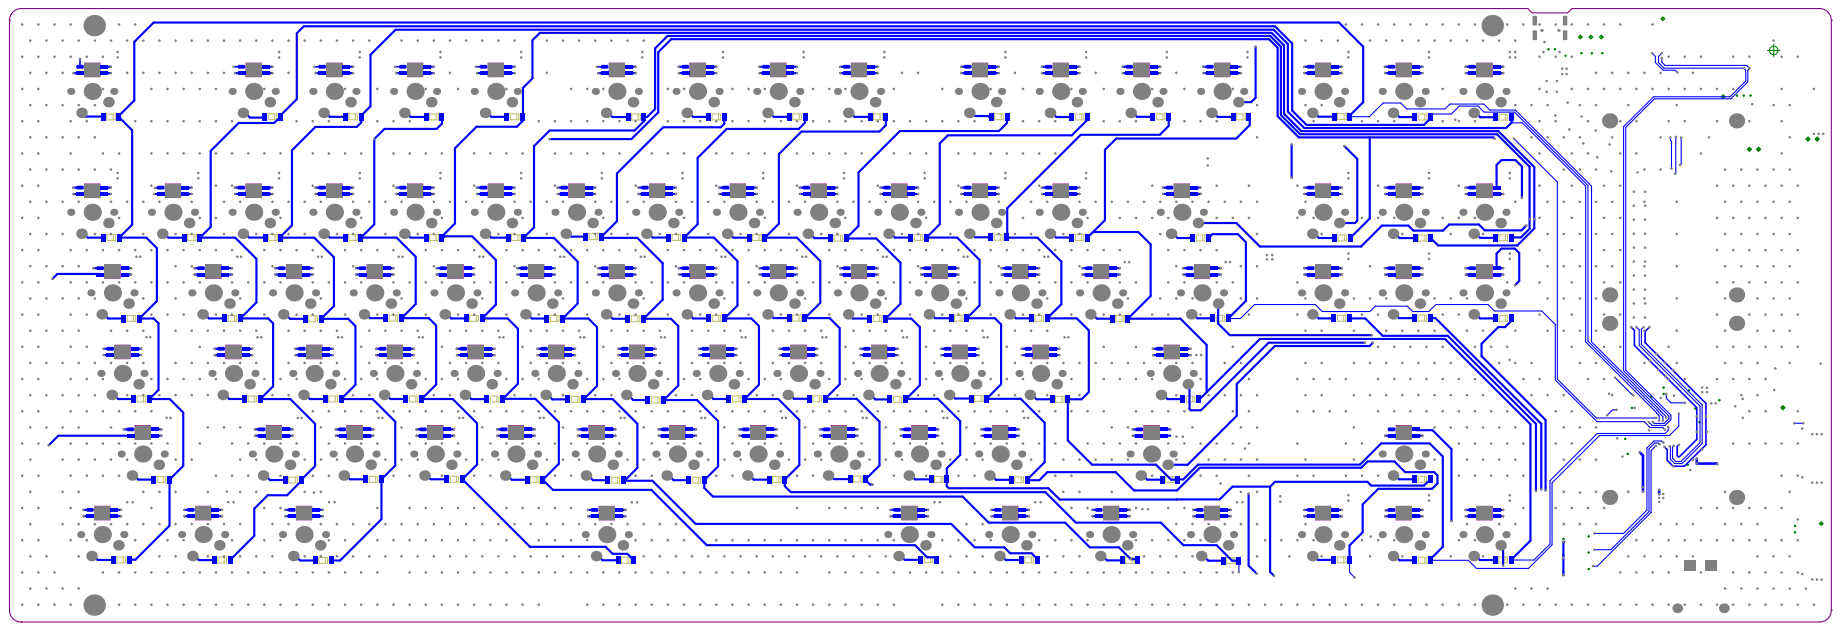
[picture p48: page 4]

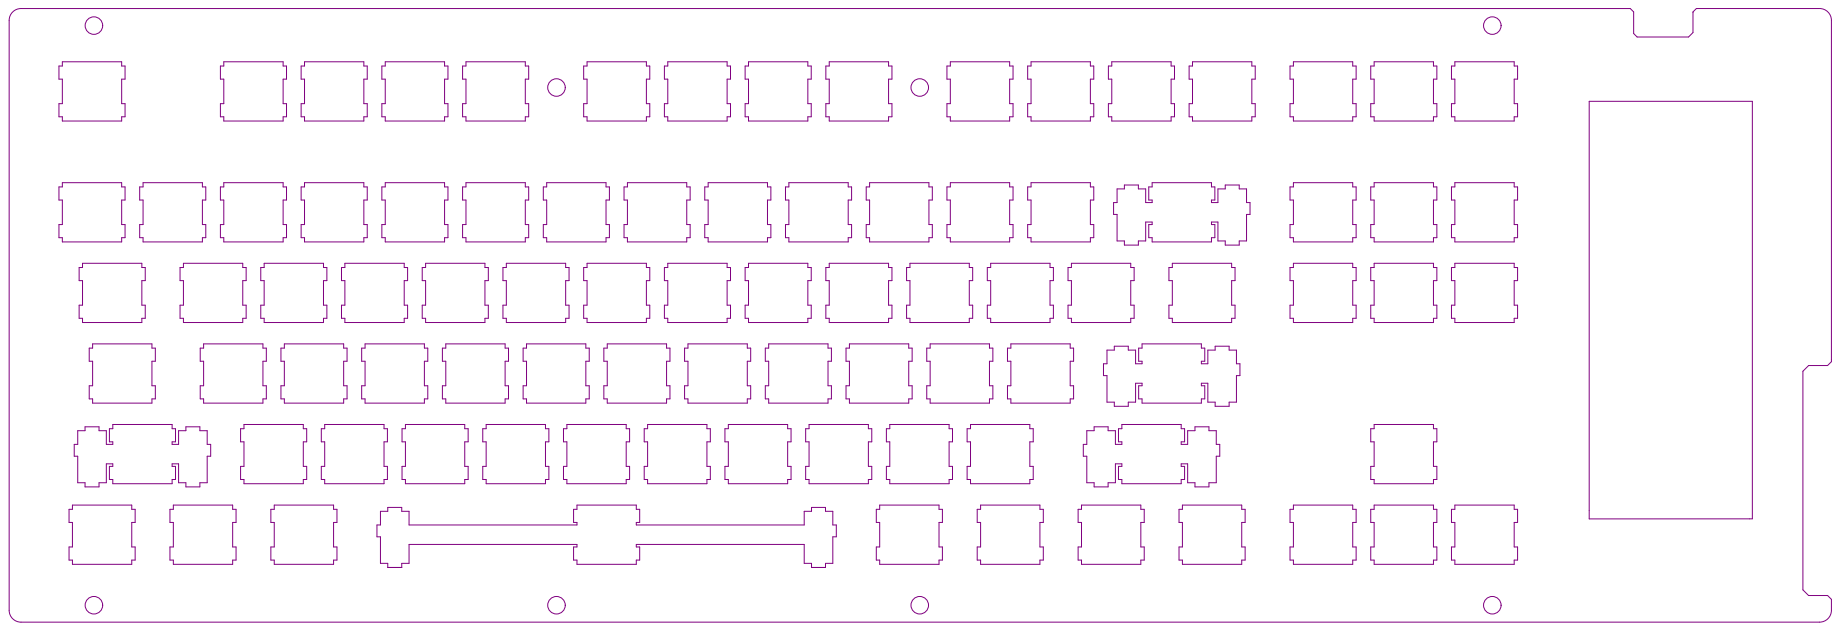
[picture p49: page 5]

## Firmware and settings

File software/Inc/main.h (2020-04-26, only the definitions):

#define KEY_POS12_Pin GPIO_PIN_13
#define KEY_POS12_GPIO_Port GPIOC
#define KEY_POS13_Pin GPIO_PIN_14
#define KEY_POS13_GPIO_Port GPIOC
#define KEY_POS14_Pin GPIO_PIN_15
#define KEY_POS14_GPIO_Port GPIOC
#define KEY_POS1_Pin GPIO_PIN_0
#define KEY_POS1_GPIO_Port GPIOC
#define KEY_POS2_Pin GPIO_PIN_1
#define KEY_POS2_GPIO_Port GPIOC
#define KEY_POS3_Pin GPIO_PIN_2
#define KEY_POS3_GPIO_Port GPIOC
#define KEY_POS4_Pin GPIO_PIN_3
#define KEY_POS4_GPIO_Port GPIOC
#define LED1_Pin GPIO_PIN_2
#define LED1_GPIO_Port GPIOA
#define BUTTON_AD_Pin GPIO_PIN_3
#define BUTTON_AD_GPIO_Port GPIOA
#define OLED_DC_Pin GPIO_PIN_4
#define OLED_DC_GPIO_Port GPIOA
#define OLED_CLK_Pin GPIO_PIN_5
#define OLED_CLK_GPIO_Port GPIOA
#define OLED_RST_Pin GPIO_PIN_6
#define OLED_RST_GPIO_Port GPIOA
#define OLED_MOSI_Pin GPIO_PIN_7
#define OLED_MOSI_GPIO_Port GPIOA
#define KEY_POS5_Pin GPIO_PIN_4
#define KEY_POS5_GPIO_Port GPIOC
#define KEY_POS6_Pin GPIO_PIN_5
#define KEY_POS6_GPIO_Port GPIOC
#define LED2_Pin GPIO_PIN_0
#define LED2_GPIO_Port GPIOB
#define KEY_SEG1_Pin GPIO_PIN_1
#define KEY_SEG1_GPIO_Port GPIOB
#define KEY_SEG2_Pin GPIO_PIN_10
#define KEY_SEG2_GPIO_Port GPIOB
#define KEY_SEG3_Pin GPIO_PIN_11
#define KEY_SEG3_GPIO_Port GPIOB
#define KEY_SEG4_Pin GPIO_PIN_12
#define KEY_SEG4_GPIO_Port GPIOB
#define KEY_SEG5_Pin GPIO_PIN_13
#define KEY_SEG5_GPIO_Port GPIOB
#define KEY_SEG6_Pin GPIO_PIN_14
#define KEY_SEG6_GPIO_Port GPIOB
#define KEY_SEG7_Pin GPIO_PIN_15
#define KEY_SEG7_GPIO_Port GPIOB
#define KEY_POS7_Pin GPIO_PIN_6
#define KEY_POS7_GPIO_Port GPIOC
#define KEY_POS8_Pin GPIO_PIN_7
#define KEY_POS8_GPIO_Port GPIOC
#define KEY_POS9_Pin GPIO_PIN_8
#define KEY_POS9_GPIO_Port GPIOC
#define KEY_POS10_Pin GPIO_PIN_9
#define KEY_POS10_GPIO_Port GPIOC
#define KEY_POS11_Pin GPIO_PIN_8
#define KEY_POS11_GPIO_Port GPIOA
#define CAN2_RX_Pin GPIO_PIN_5
#define CAN2_RX_GPIO_Port GPIOB
#define CAN2_TX_Pin GPIO_PIN_6
#define CAN2_TX_GPIO_Port GPIOB
#define DIN_3V3_1_Pin GPIO_PIN_7
#define DIN_3V3_1_GPIO_Port GPIOB
#define DIN_3V3_2_Pin GPIO_PIN_8
#define DIN_3V3_2_GPIO_Port GPIOB
#define DIN_3V3_3_Pin GPIO_PIN_9
#define DIN_3V3_3_GPIO_Port GPIOB

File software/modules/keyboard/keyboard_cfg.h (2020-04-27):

#ifndef _KEYBOARD_CFG_H
#define _KEYBOARD_CFG_H
#include "struct_typedef.h"
#define MAX_KEYPAD_PAGE 104
#define STACK_POINT_LENGTH 6
/*键盘按键枚举*/
typedef enum
{
    Key_board_Null = 0,
    Keyboard_a =4,// Keyboard a and A
    Keyboard_b=5,// Keyboard b and B
    Keyboard_c=6,// Keyboard c and C
    Keyboard_d=7,// Keyboard d and D
    Keyboard_e=8,// Keyboard e and E
    Keyboard_f=9,// Keyboard f and F
    Keyboard_g=10,// Keyboard g and G
    Keyboard_h=11,// Keyboard h and H
    Keyboard_i=12,// Keyboard i and I
    Keyboard_j=13,// Keyboard j and J
    Keyboard_k=14,// Keyboard k and K
    Keyboard_l=15,// Keyboard l and L
    Keyboard_m=16,// Keyboard m and M
    Keyboard_n=17,// Keyboard n and N
    Keyboard_o=18,// Keyboard o and O
    Keyboard_p=19,// Keyboard p and P
    Keyboard_q=20,// Keyboard q and Q
    Keyboard_r=21,// Keyboard r and R
    Keyboard_s=22,// Keyboard s and S
    Keyboard_t=23,// Keyboard t and T
    Keyboard_u=24,// Keyboard u and U
    Keyboard_v=25,// Keyboard v and V
    Keyboard_w=26,// Keyboard w and W
    Keyboard_x=27,// Keyboard x and X
    Keyboard_y=28,// Keyboard y and Y
    Keyboard_z=29,// Keyboard z and Z
    Keyboard_1=30,// Keyboard 1 and !
    Keyboard_2=31,// Keyboard 2 and @
    Keyboard_3=32,// Keyboard 3 and #
    Keyboard_4=33,// Keyboard 4 and $
    Keyboard_5=34,// Keyboard 5 and %
    Keyboard_6=35,// Keyboard 6 and ^
    Keyboard_7=36,// Keyboard 7 and &
    Keyboard_8=37,// Keyboard 8 and *
    Keyboard_9=38,// Keyboard 9 and (
    Keyboard_0=39,// Keyboard 0 and )
    Keyboard_ENTER=40,// Keyboard ENTER 
    Keyboard_ESCAPE=41,// Keyboard ESCAPE
    Keyboard_Backspace=42,// Keyboard Backspace
    Keyboard_Tab=43,// Keyboard Tab
    Keyboard_KongGe=44,// Keyboard Spacebar
    Keyboard_JianHao=45,// Keyboard - and _(underscore)
    Keyboard_DengHao=46,// Keyboard = and +
    Keyboard_ZuoZhongKuoHao=47,// Keyboard [ and {
    Keyboard_YouZhongKuoHao=48,// Keyboard ] and }
    Keyboard_FanXieGang= 49,// Keyboard \ and |
    Keyboard_FenHao=51,// Keyboard ; and :
    Keyboard_DanYinHao= 52,// Keyboard ‘ and “
    Keyboard_BoLangXian= 53,// Keyboard `(Grave Accent) and ~(Tilde)
    Keyboard_Douhao=54,// Keyboard, and <
    Keyboard_JuHao=55,// Keyboard . and >
    Keyboard_XieGang_WenHao=56,// Keyboard / and ?
    Keyboard_CapsLock=57,// Keyboard Caps Lock
    Keyboard_F1=58,// Keyboard F1
    Keyboard_F2=59,// Keyboard F2
    Keyboard_F3=60,// Keyboard F3
    Keyboard_F4=61,// Keyboard F4
    Keyboard_F5=62,// Keyboard F5
    Keyboard_F6=63,// Keyboard F6
    Keyboard_F7=64,// Keyboard F7
    Keyboard_F8=65,// Keyboard F8
    Keyboard_F9=66,// Keyboard F9
    Keyboard_F10= 67,// Keyboard F10
    Keyboard_F11= 68,// Keyboard F11
    Keyboard_F12= 69,// Keyboard F12
    Keyboard_PrintScreen=70,// Keyboard PrintScreen
    Keyboard_ScrollLock= 71,// Keyboard Scroll Lock
    Keyboard_Pause=72,// Keyboard Pause
    Keyboard_Insert=73,// Keyboard Insert
    Keyboard_Home= 74,// Keyboard Home
    Keyboard_PageUp=75,// Keyboard PageUp
    Keyboard_Delete=76,// Keyboard Delete
    Keyboard_End=77,// Keyboard End
    Keyboard_PageDown=78,// Keyboard PageDown
    Keyboard_RightArrow=79,// Keyboard RightArrow
    Keyboard_LeftArrow=80,// Keyboard LeftArrow
    Keyboard_DownArrow= 81,// Keyboard DownArrow
    Keyboard_UpArrow=82,// Keyboard UpArrow
    Keypad_NumLock=83,// Keypad Num Lock and Clear
    Keypad_ChuHao=84,// Keypad /
    Keypad_ChengHao=85,// Keypad *
    Keypad_JianHao=86,// Keypad -
    Keypad_JiaHao=87,// Keypad +
    Keypad_ENTER=88,// Keypad ENTER
    Keypad_1_and_End=89,// Keypad 1 and End
    Keypad_2_and_DownArrow=90,// Keypad 2 and Down Arrow
    Keypad_3_and_PageDn= 91,// Keypad 3 and PageDn
    Keypad_4_and_LeftArrow=92,// Keypad 4 and Left Arrow
    Keypad_5=93,			// Keypad 5
    Keypad_6_and_RightArrow=94,// Keypad 6 and Right Arrow
    Keypad_7_and_Home=95,// Keypad 7 and Home
    Keypad_8_and_UpArrow=96,// Keypad 8 and Up Arrow
    Keypad_9_and_PageUp= 97,// Keypad 9 and PageUp
    Keypad_0_and_Insert= 98,// Keypad 0 and Insert
    Keypad_Dian_and_Delete=99,// Keypad . and Delete
    Keyboard_Application=101,// Keyboard Application
	Keyboard_Menu=118,
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

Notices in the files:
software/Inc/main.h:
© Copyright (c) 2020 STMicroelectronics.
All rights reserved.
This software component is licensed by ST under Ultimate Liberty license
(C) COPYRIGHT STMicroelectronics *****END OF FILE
